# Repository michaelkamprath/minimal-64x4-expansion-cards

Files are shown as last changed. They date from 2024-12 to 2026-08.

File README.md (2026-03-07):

# Expansion Cards for Minimal 64x4 Computer
This repository contains various expansion cards for the [Minimal 64x4 Home Computer](https://github.com/slu4coder/Minimal-64x4-Home-Computer/) design by Carsten Herting, known as [slu4 on YouTube](https://www.youtube.com/channel/UCXYQcMpUBT3aaQKfmAVJNow).

## Back Plane
The [back plane provided in this repository](./expansion-backplane/) allows for more than one expansion card to be connected to the Minimal 64x4. It also provides a more convenient barrel jack power connector with a on/off switch to power the Minimal 64x4.

## Cards

* [**Speech Synthesizer**](./speech-synthesizer/) - This board provides support for interfacing with a TMS5220C speech synthesizer. 
* [**Multiplier Card**](./multiplier/) - This board provides a hardware implimentation of 8-bit integer multiplications, significantly improving the speed of multiplications over software-implementations.
* [**Timer**](./timer/) - Counts the cycles of the Minimal 64x4's system clock to enable precision timing of events.

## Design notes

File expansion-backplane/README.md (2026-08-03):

# Expansion Backplane for Minimal 64x4 Computer

This backplane allows connecting of up to 4 expansion cards to the Minimal 64x4 computer. The [expansion connector](./hardware/expansion-connector/) is a convenient way to connect the backplane to the Minimal 64x4 computer.

### Shared `INH` Line
To have multiple cards connected to the backplane, they need to share the active high `INH` inhibit line. If multiple cards are emitting a LOW signal directly, and one emits a HIGH, contention will occur. To prevent such contention, the back plane uses a 74AHCT126 to arbitrate the `INH` signal's progression from a card to the Minimal 64x4's exansion port. Each of the buffers in the 74AHCT126 have their input signal tied high, and the each card's `INH` output us used to control the output enable for it's assigned buffer. In this way, when a card's `INH` output is low (not active), it's corresponding buffer has its output in a high-Z state. So if another card asserts it's `INH` line high, there won't be bus contention back to the card. But each card's active high `INH` signal is passed through to the Minimal 64x4. The downside is that each expansion card cannot monitor whether another card is asserting the `INH` signal. This is not deemed to be a signficant issues since Minimal 64x4 expansion board are generally memory mapped, and thus only one can be actively writing to the bus at a time.

### Card Address Assignment
The data bus has **no arbitration** — the `INH` scheme above protects only the inhibit line. Correctness depends entirely on one card decoding a given address. Because address lines settle at different times during a bus transition, a card can transiently match another card's address and drive the bus against it, so assign base addresses to maximize the **Hamming distance of the decoded address bits**, not the hex separation.

| Card | Base | Decoded `A7..A3` |
| --- | --- | --- |
| Multiplier | `$FED0` | `11010` |
| Timer | `$FE28` | `00101` |

**Failure signature** (seen 2026-08 with the timer at `$FEF0`, one bit from the multiplier): reads from the victim card return wrong values intermittently, writes and RAM are fine, results vary run to run *and* between builds as code shifts, and software-only builds are perfect. Diagnose by moving one card, not by debugging the software.

Two mechanisms produce this and are **not yet distinguished**: address-line skew, or the 74HCT688 comparator glitching its output during input transitions. If it's the latter, bit distance is only probabilistic protection and a gated `/G` or delayed enable is needed. To measure: reinstate the colliding address, run `multiplier/software/test_karatsuba_layers.min64x4` (fails ~30% of 65536 cases, so events are continuous), and trigger a logic analyzer on *the victim card's decode asserting while the address belongs to the other card*.

Note that CLK-gating a card's read output enable is **not** a fix: the address and `RI`/`RO` are set on the falling edge and the selected card must be driving the bus before the rising edge latches it, so the read enable has to be live during the settling window by design.

### Power Barrel Jack
The back plane provides a convenient standard 2.1 mm barrel jack you may use to connect to a regulated `5V` power supply to power the expansion cards and additionally power the Minimal 64x4 computer. If this barrel jack is connected to power, be sure to not connect the UART's `+5V` line to the Minimal 64x4 (still connect `GND`)

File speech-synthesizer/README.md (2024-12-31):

# TMS5220 Speech Synthesizer for Minimal 64x4 Computer
This project creates a TMS5220-based speech synthesizer board for the [Minimal 64x4](https://github.com/slu4coder/Minimal-64x4-Home-Computer) expansion port. The high-level design criteria are:

1. **Accommodate the “slow memory” nature of the TMS5220** by using hardware to buffer the interactions between the CPU and the TMS5220 such that the CPU is free to do other tasks while the TMS5220 processes data. This contrasts with typical 1980s computer hardware designs, which would halt the CPU while the TMS5220 processed data.
2. **Only support “external” speech data; PHROMs are not supported.** Not supporting PHROMs greatly simplifies the board and saves money, as original PHROMs are hard to come by in the modern age. Most games of the 1980s did not use PHROM data, instead providing their own LPC-encoded speech data.

This board supports both the TMS5220 and TMS5220C variants of the speech synthesizer chip.

## Hardware Design
The board responds to three memory-mapped addresses (the board is adjustable to set the `_` value below, but it defaults to `0xC`):

* `0xFE_0` – **TMS5220 Command Register**
  This address allows the host computer to write data to the TMS5220’s command register, which is used for sending “external speech” data to the TMS5220. In general, the host computer will write certain TMS5220 commands and speech data to this address.

* `0xFE_1` – **TMS5220 Status Register**
  This address allows the host computer to fetch the internal TMS5220 status register. To do that, the host computer writes some data to this address (any value, as the value is not actually used) to start the sequence of events to get the internal status from the TMS5220. When this is done, the status value will be readable by the host computer at this address. The status data being ready is indicated by the board’s `BUSY` line, which is readable at the **Board Status Register**. The `BUSY` line will be asserted high from the moment this address is written to until the status value is ready to be read.

* `0xFE_2` – **Board Status Register**
  This address exposes several internal states of this board, independent of the TMS5220, and can be read by the host computer at any time. The individual bits within the byte value read are below. Of these lines, the host computer generally only interacts with the `/INT` and `BUSY` bits.

  * **bit 0 – `BUSY`**
    Indicates whether the TMS5220 or the board, in general, is working on something. The host computer should not interact with the TMS5220 Command or Status registers while this bit is high.
  * **bit 1 – `/INT`**
    The current value of the active-low interrupt line coming out of the TMS5220. When this bit is low, it indicates that the TMS5220 requires attention. The specific issue can be determined by reading the TMS5220 Status Register.
  * **bit 2 – `/READY`**
    The current value of the active-low `READY` line out of the TMS5220. Host computer software should use the `BUSY` line to arbitrate interaction with the board, but the `READY` line is exposed here for diagnostic purposes.
  * **bit 3 – `WS`**
    The current status of the `WS` flip flop (active high). Exposed for diagnostic purposes.
  * **bit 4 – `RS`**
    The current status of the `RS` flip flop (active high). Exposed for diagnostic purposes.

* `0xFE_3` – **TMS5220C Reset** – *Currently Unimplemented*
  The TMS5220C variant can be reset by holding both the `/RS` and `/WS` lines low at the same time. This action has undefined results for the non-C TMS5220 variant.

### TMS5220 “Slow Memory” Issue
A key pin to understand on the TMS5220 is the `READY` signal at pin 18. The TMS5220 drives the `READY` pin low when it is ready to accept input or provide output to the host computer. When the `READY` pin is high, the TMS5220 is busy processing data and does not immediately act on—if not outright ignore—any interactions the CPU initiates. In many 1980s-era computers, the `READY` pin was connected to the CPU’s halt or wait-state pin, causing the CPU to stop while the TMS5220 processed data. This board takes a different approach. In some ways, this is necessary because the Minimal 64x4 has no line that would allow an accessory to pause or halt the CPU. However, this design choice is otherwise agnostic of that limitation.

As a result, data interactions between the host computer and the TMS5220 must be cached to handle the timing differences. The key to caching these CPU interactions is the ATF22V10C programmable logic chip and the 74HCT74 flip flops. The flip flops hold the `/WS` and `/RS` signals on the TMS5220, and the ATF22V10C is programmed to create a state machine that manages these flip flops. For example, here is the sequence of events for writing a byte of data to the TMS5220:

1. When the address bus is set to the memory-mapped address of `0xFEC0`, the 74HCT688s will assert this `MMAP` line, and the `M0` and `M1` address lines will be 0. To write to the TMS5220, the host computer `/RI` line will be asserted. The ATF22V10C’s programmable logic then asserts `WS_CLK`, which is the clock line that drives the `WS` flip flop, in turn asserting the active-low `/WS` line to the TMS5220. This tells the TMS5220 that we want to write data to its data lines.
2. At the same time `WS_CLK` causes the `WS` flip flop to set its state, `WS_CLK` also causes the data bus input 74HCT374 flip flop to load the contents of the host computer’s data bus. Because of this, the expansion board can capture and hold the data bus value the host computer is writing to the TMS5220, allowing the host computer to move on to other tasks while this flip flop holds the data bus value. Furthermore, the `/WS` line to the TMS5220 also drives the output enable on the 74HCT374 octal flip flop, so the buffered data will be held and driven onto the board’s internal data bus for the entire time `/WS` is low—even as the host computer does other work. This is the essence of the “slow memory” issue: the TMS5220 requires several host-computer clock cycles to read in the data, and its data lines must be held for the entire duration. The 74HCT374 flip flop buffers the data and holds the lines active as long as needed.
3. In response to the `/WS` line being asserted, the TMS5220 drives the `READY` line high. When this occurs, the ATF22V10C waits until the `READY` line transitions from high to low, which indicates that the TMS5220 has finished processing the input data. When the `READY` line goes low, the ATF22V10C then asserts `WS_RST`, the reset line for the `WS` flip flop. This brings `/WS` high, which tells the TMS5220 that the write operation is complete. It also disables the output enable on the 74HCT374 that was buffering the data. In this way, `/WS` remains asserted until the TMS5220 indicates it is done reading the data from the buffers, as indicated by the `READY` line.
4. During this entire sequence, the ATF22V10C asserts the `BUSY` line for the board, which can be read by the host computer at address `0xFE_2` via the 74HCT245. This allows the host computer to query the board to see if the TMS5220 is done processing data.

A similar sequence is used when reading data from the TMS5220, centered around the `/RS` line.

### Undocumented Timing Issues
The TMS5220 appears to have some timing requirements that are not documented in its datasheet. These requirements were exposed by the Minimal 64x4, which runs at a clock speed faster than the typical host computers for which the TMS5220 was designed. These undocumented timing requirements were determined empirically and could likely be tweaked further:

* **Read Cycle for Status Transfers to External Speech Data Write**
  The datasheet indicates that the `t_wait` after `/RS` goes high is 12 µs. However, I found that something closer to 175 µs was needed between a status read and a subsequent external speech data write.

* **External Speech Data Write to Read Cycle for Status Transfers**
  Similarly, extra time is needed between writing external speech data and then reading the TMS5220 status. Again, I found that about 175 µs was needed.

These values were “tweaked until it worked.” The issues seem related to switching modes of interaction with the TMS5220. By contrast, writing an external speech data byte after a prior external speech data byte does adhere to the timing diagrams in the TMS5220 datasheet. Further experimentation might uncover better or smaller delays for these undocumented requirements.

## Software Design
The provided `speechlib.min64x4` file contains all the subroutines needed to use this board on the Minimal 64x4 home computer:

* `speech_init`
  Call this to initialize the board.

* `speak_synchronous`
  Speaks the LPC data in a passed buffer synchronously. Push the following arguments on the stack (in push order):
  1. **Buffer End Address** – 2-byte end address of the data buffer
  2. **Buffer Start Address** – 2-byte start address of the data buffer

* `speech_start`
  Speaks the LPC data in a passed buffer asynchronously, after synchronously waiting for any currently active talking to finish. Push the following arguments on the stack (in push order):
  1. **Buffer End Address** – 2-byte end address of the data buffer
  2. **Buffer Start Address** – 2-byte start address of the data buffer

* `speech_start_if_not_talking`
  Speaks the LPC data in a passed buffer asynchronously if there is no currently active speech. Push the following arguments on the stack (in push order):
  1. **Buffer End Address** – 2-byte end address of the data buffer
  2. **Buffer Start Address** – 2-byte start address of the data buffer

* `speech_update_buffer`
  Call this periodically (about every 1 ms) to enable asynchronous speech. No arguments.

* `speech_get_status`
  Gets the contents of the TMS5220 status register, which is returned in the `A` register. The following bit masks are defined to help interpret the results:
  * `SPEECH_STATUS_TALK` – The TMS5220 is currently talking.
  * `SPEECH_STATUS_BUFFER_LOW` – The TMS5220 FIFO buffer is half-empty. More LPC data needs to be sent.
    *_Note_*: The `speech_update_buffer` function automatically updates the FIFO if needed.
  * `SPEECH_STATUS_BUFFER_EMPTY` – The TMS5220 FIFO buffer is empty.

# Compiling the Software
All software found in the [software](./software/) directory is compiled with [BespokeASM](https://github.com/michaelkamprath/bespokeasm), which supports the Minimal 64x4. [Carsten Herting](https://github.com/slu4coder), the creator of the Minimal 64x4, also provides an assembler for it, but that assembler is quite minimal. One key shortcoming is the inability to import library code into the current compilation. BespokeASM enables importing libraries and includes several other features that this project’s software depends on.

To compile the speech code in this repository, use the following command:

```sh
bespokeasm compile -c /path/to/bespokeasm/examples/slu4-minimal-64x4/slu4-minimal-64x4.yaml -n -p -t intel_hex lpc_player.min64x4
```
Where `/path/to/bespokeasm` is the path to the BespokeASM repository on your computer. This will produce an Intel HEX representation of the compiled program, which can then be sent to the Minimal 64x4 using its `receive` command.

# Resources
The following resources I found useful when putting together this project

* [TMS5220 Datasheet](./datasheets/tms5220.pdf) - Always consult the datasheet first.
* [Thierry Nouspikel's "The Speech Synthesizer module"](https://www.unige.ch/medecine/nouspikel/ti99/speech.htm) - A detailed overview of how the TMS5220 is used in the TI 99/4a.
* [TI 99/4a Development forum on AtariAge](https://forums.atariage.com/topic/352156-looking-for-help-on-tms5220-circuit-software-design-and-usage/) - These folks are legends, helpful and knowledgable about anything related to Texas Instruments.

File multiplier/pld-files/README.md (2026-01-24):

# `PLD` Files for Programmable Logic

## Compiling PLD
The `.pld` files in this directory may be compiled with [GALasm](https://github.com/daveho/GALasm) or [galette](https://github.com/simon-frankau/galette), producing a `.jed` file amonst others. Then the `.jed` file is used to program a `ATF16V8C` or `GAL16V8`.

```sh
galasm multiplier-board-controller.pld
```

## Programming the 22V10
The `ATF16V8C` type should be used when programming the ATF16V8C with `minipro`.

```sh
minipro -p "ATF16V8C" -w multiplier-board-controller.jed
```

## More Information
More information about programmable logic devices can be found at these links:
* [Understanding Programmable Logic - The GAL22V10](https://retrobrewcomputers.org/n8vem-pbwiki-archive/0/82152589/Programmable%20logic%20devices%20-%20v1.6.pdf) - A good overviews of what programmable logic devices are.
* [Galette](https://github.com/simon-frankau/galette) - an alternative GAL PLD assembler
* [GAL-ASM-Starterkit](https://www.mikrocontroller.net/attachment/20953/GAL-ASM-Starterkit_Manual.pdf) - Documentation the PLD file syntax from another PLD assembler.

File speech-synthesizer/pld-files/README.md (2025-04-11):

# `PLD` Files for Programmable Logic

## Compiling PLD
The `.pld` files in this directory may be compiled with [GALasm](https://github.com/daveho/GALasm), producing a `.jed` file amonst others. Then the `.jed` file is used to program a `ATF22V10C` or `GAL22V10`.

```sh
galasm minimal-64x4-speech-controller.pld
```

## Programming the 22V10
The `ATF22V10C(UES)` type should be used when programming the ATF22V10C with `minipro`.

```sh
minipro -p "ATF22V10C(UES)" -w minimal-64x4-speech-controller.jed
```

## More Information
More information about programmable logic devices can be found at these links:
* [Understanding Programmable Logic - The GAL22V10](https://retrobrewcomputers.org/n8vem-pbwiki-archive/0/82152589/Programmable%20logic%20devices%20-%20v1.6.pdf) - A good overviews of what programmable logic devices are.
* [Galette](https://github.com/simon-frankau/galette) - an alternative GAL PLD assembler
* [GAL-ASM-Starterkit](https://www.mikrocontroller.net/attachment/20953/GAL-ASM-Starterkit_Manual.pdf) - Documentation the PLD file syntax from another PLD assembler.

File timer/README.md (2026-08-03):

# Timer - Clock Counter
This Timer card provides a convenient way to capture precise timing on the Minimal 64x4 by counting clock cycles. The counter is resettable to 0, allowing specific operations to be timed. The counter is 48 bits wide, which allows time ranges up to about 1.1 years at the Minimal 64x4's 8 MHz clock frequency.

## Hardware Design
[This card](./hardware/) uses six 74HC590 8-bit counters arranged in a cascading carry chain to create a 48-bit counter. The 74HC590 has tri-state outputs, so each counter IC is connected directly to the data bus and remains in high-Z unless selected to drive its latched value. Card control is handled by two 74HC688 comparators (address decode) and an ATF22V10C programmable logic device (control logic for read byte select, latch, and reset). The combinational logic is captured in [the PLD code](./pld-files/).

## Memory Map

Define:

`base = $FE00 + (x << 4) + y`

Where:
- `y` is controlled by jumper `J1` (address bit A3): `J1` open => `y = 0`, `J1` bridged => `y = 8`.
- `x` is controlled by jumpers `J2`-`J5` (address bits A4-A7): `J2` is A4 (LSB of `x`) and `J5` is A7 (MSB of `x`).
- Jumpers are named from the PCB silkscreen (`J1`-`J5`).

| Offset From `base` | R/W | Function | Description |
| --- | ----- | --- | --- |
| `+0` | Read  | Latched Byte 0 | Read latched counter value, byte 0 (LSB) |
| `+1` | Read  | Latched Byte 1 | Read latched counter value, byte 1 |
| `+2` | Read  | Latched Byte 2 | Read latched counter value, byte 2 |
| `+3` | Read  | Latched Byte 3 | Read latched counter value, byte 3 |
| `+4` | Read  | Latched Byte 4 | Read latched counter value, byte 4 |
| `+5` | Read  | Latched Byte 5 | Read latched counter value, byte 5 (MSB) |
| `+6` | Write | Latch Counter  | Latch (snapshot) the current 48-bit counter into the output registers. Any value may be written to trigger this action. |
| `+7` | Write | Reset Counter  | Reset the counter value to `0`. Any value may be written to trigger this action. |

Concrete ranges for a selected `x`:
- `J1` open (`y = 0`): registers are at `$FEx0`-`$FEx7`.
- `J1` bridged (`y = 8`): registers are at `$FEx8`-`$FExF`.

Notes:
- Bridging all jumpers `J2` through `J5` sets `x` to `$F`; leaving them open sets `x` to `$0` (default).
- Reading `$FEx0`-`$FEx5` (or `$FEx8`-`$FExD` when `J1` is bridged) returns the last value latched by writing to the latch register, not necessarily the current counter value.
- Resetting the counter does not latch a `0` value.

### Default Jumper Setttings
The code in this repo assumes the timer card's base address is $FE28. This is accomplished by jumpering J1 and J3, and leaving the others open.

## Time Range
This card has a 48-bit counter that is read one byte at a time. Not all bytes need to be read, but reading fewer bytes reduces the effective time range captured. At the **Minimal 64x4**'s 8 MHz clock, the maximum time range by number of bytes read is shown in this table:

| Bytes | Bits | Max Seconds (s) | Approx Time |
| ----: | ---: | ---: | --- |
| 6 | 48 | 35184372.088832 | 407.22652996 days (~1.115 years) |
| 5 | 40 | 137438.953472 | 38.17748708 hours (~1.5907 days) |
| 4 | 32 | 536.870912 | 8.94784853 minutes |
| 3 | 24 | 2.097152 | 2.097152 seconds |
| 2 | 16 | 0.008192 | 8.192 ms |
| 1 | 8 | 0.000032 | 32 µs |

The latched bytes are arranged in little-endian order: `base + 0` is the LSB and `base + 5` is the MSB.

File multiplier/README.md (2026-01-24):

# Integer Multiplication Accelerator for the Minimal 64x4 Computer
This project enables hardware-accelerated multiplication on the [Minimal 64x4 Home Computer](https://github.com/slu4coder/Minimal-64x4-Home-Computer/), exploring how multiplication works at a fundamental level in both software and hardware, using the Minimal 64x4 homebrew computer as a real-world test platform. Starting with a classic shifted-add multiplication algorithm implemented entirely in assembly, the project demonstrates both the mechanics and performance limits of software-based multiplication on an 8-bit CPU.

To dramatically improve performance, a dedicated hardware multiplier card is designed and built using discrete 74-series logic. The board implements a fully combinational 8-bit × 8-bit multiplier with memory-mapped I/O, allowing the CPU to offload multiplication and receive a 16-bit result in just a few clock cycles. The design is then extended in software to support full 16-bit × 16-bit multiplication through careful carry management.

The impact of hardware acceleration is demonstrated using a Mandelbrot renderer, where thousands of multiplications per frame make performance differences immediately visible. By comparing software-only and hardware-accelerated runs on real hardware, the project shows how a simple, purpose-built coprocessor can transform computational performance on a retro-style system.

# Hardware Multiplier Design
The hardware multiplier is a memory-mapped expansion board for the Minimal 64x4 that implements an 8-bit × 8-bit unsigned multiplication entirely in combinational logic. The design uses a planar array of 74AHCT08 AND gates to generate all partial products, followed by a cascade of 74HCT283 4-bit adders to sum those partial products and propagate carries. Because the multiplier core is purely combinational, no clocking, state machine, or control logic is required; once valid operands are presented, the result settles after the inherent gate propagation delay.

Operands are latched from the system data bus using 74AHCT374 registers to isolate the combinational logic from the shared bus and to ensure stable inputs during computation. The 16-bit result is continuously driven internally and presented to the host system through 74AHCT245 bidirectional bus transceivers when the board is selected. Address decoding is handled using 74HCT688 magnitude comparators, with a small programmable logic device (ATF16V8) providing glue logic for timing, output enable control, and bus arbitration.

Worst-case propagation delay is dominated by carry propagation through the adder array and is approximately 160 ns, corresponding to roughly two CPU cycles on an 8 MHz Minimal 64x4. From the CPU’s perspective, multiplication is reduced to a small number of memory writes and reads, enabling a substantial performance improvement over the software-only shifted-add implementation.

```text
                     ┌─────────────────────────┐
                     │        CPU / BUS        │
                     │  Address • Data • Ctrl  │
                     └───────────┬─────────────┘
                                 │
                        Memory-Mapped I/O
                                 │
        ┌────────────────────────▼────────────────────────┐
        │            Hardware Multiplier Board            │
        │                                                 │
        │  ┌───────────────┐      ┌────────────────────┐  │
        │  │ Input Latch A │◄─────┤                    │  │
        │  │  (8-bit)      │      │                    │  │
        │  └───────────────┘      │                    │  │
        │                         │                    │  │
        │  ┌───────────────┐      │  Combinational     │  │
        │  │ Input Latch B │◄─────┤  Multiplier Core   │  │
        │  │  (8-bit)      │      │  (AND Plane +      │  │
        │  └───────────────┘      │   Adder Array)     │  │
        │                         │                    │  │
        │                         │                    │  │
        │                         └─────────┬──────────┘  │
        │                                   │             │
        │                          16-bit Result          │
        │                                   │             │
        │                    ┌──────────────▼────────────┐│
        │                    │  Output Bus Transceivers  ││
        │                    │       (16-bit)            ││
        │                    └──────────────┬────────────┘│
        │                                   │             │
        │  ┌──────────────────────────┐     │             │
        │  │ Address Decode & Control │◄────┘             │
        │  │ (Comparators + PLD)      │                   │
        │  └──────────────────────────┘                   │
        └─────────────────────────────────────────────────┘
```
The overall structure of the hardware multiplier is shown in the block diagram above. The board interfaces with the CPU exclusively through memory-mapped I/O on the shared system bus. Operand values are written by the CPU into two 8-bit input latches (Operand A and Operand B), which isolate the multiplier core from bus activity and continuously present stable inputs to the combinational logic.

At the center of the design is a purely combinational multiplier core composed of an AND-gate partial-product plane followed by an adder array that collapses those partial products into a 16-bit result. Because the core has no internal state, clocking, or control signals, the result is produced automatically as signals propagate through the logic once the operands are latched.

The 16-bit result is connected to the system data bus through output bus transceivers that are enabled only during valid read cycles. Address decoding and timing control logic ensure the board responds only within its assigned address range and never drives the bus outside of those cycles. From the CPU’s perspective, the hardware multiplier appears as a small set of deterministic, memory-mapped registers, with computation latency bounded solely by combinational propagation delay.

# Compiling the Software
All software found in the [software](./software/) directory is compiled with [BespokeASM](https://github.com/michaelkamprath/bespokeasm), which supports the Minimal 64x4. [Carsten Herting](https://github.com/slu4coder), the creator of the Minimal 64x4, also provides an assembler for it, but that assembler is quite minimal (by design). One key shortcoming is the inability to import library code into the current compilation. BespokeASM enables importing libraries and includes several other features that this project’s software depends on.

To compile the speech code in this repository, use the following command:

```sh
bespokeasm compile -c /path/to/bespokeasm/examples/slu4-minimal-64x4/slu4-minimal-64x4.yaml -n -p -t intel_hex -D USE_ACCELERATOR mandelbrot.min64x4
```
Where `/path/to/bespokeasm` is the path to the BespokeASM repository on your computer. You may remove the `-D USE_ACCELERATOR` if you wish to compile the program to use software-only multiplication.

This will produce an Intel HEX representation of the compiled program, which can then be sent to the Minimal 64x4 using its `receive` command.

# Video

A Homebrew GPU for a Homebrew CPU (https://youtu.be/M8dk0JpkrbY)

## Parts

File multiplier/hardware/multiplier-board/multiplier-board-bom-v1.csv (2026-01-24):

Reference | Qty | Value | DNP | Exclude from BOM | Exclude from Board | Footprint | Datasheet | Mouser Part Number
C1,C2,C3,C4,C5,C6,C7,C8,C9,C10,C11,C12,C13,C14,C15,C16,C17,C18,C19,C20,C21,C22,C23,C24,C25,C26,C27,C28,C29,C30,C31,C32,C33,C34,C35,C36,C37 | 37 | 100 nF |  |  |  | Capacitor_SMD:C_0805_2012Metric_Pad1.18x1.45mm_HandSolder | ~ | 80-C0805C104M5R
CN1 | 1 | ~ |  |  |  | Connector_PinHeader_2.54mm:PinHeader_2x16_P2.54mm_Horizontal |  | 538-90122-0128
JP1,JP2,JP4 | 3 | SolderJumper_2_Bridged |  | Excluded from BOM |  | Jumper:SolderJumper-2_P1.3mm_Bridged_RoundedPad1.0x1.5mm | ~ | ~
JP3 | 1 | SolderJumper_2_Open |  | Excluded from BOM |  | Jumper:SolderJumper-2_P1.3mm_Open_RoundedPad1.0x1.5mm | ~ | ~
RN1 | 1 | 10K |  |  |  | Resistor_THT:R_Array_SIP5 | http://www.vishay.com/docs/31509/csc.pdf | 652-4605M-1LF-10K
U1,U2,U3,U4,U5,U6,U7,U8,U11,U12,U13,U14,U15,U16,U17,U18 | 16 | 74AHCT08 |  |  |  | Package_SO:SOIC-14_3.9x8.7mm_P1.27mm | http://www.ti.com/lit/gpn/sn74LS08 | 771-AHCT08D118
U9,U10 | 2 | 74HCT688 |  |  |  | Package_SO:SOIC-20W_7.5x12.8mm_P1.27mm | http://www.ti.com/lit/gpn/sn74LS688 | 771-AHCT08D118
U19 | 1 | ATF16V10C |  |  |  | Package_DIP:DIP-20_W7.62mm_Socket | https://ww1.microchip.com/downloads/en/DeviceDoc/Atmel-0425-PLD-ATF16V8C-Datasheet.pdf | 771-AHCT08D118
U20,U28 | 2 | 74AHCT374 |  |  |  | Package_SO:SOIC-20W_7.5x12.8mm_P1.27mm | http://www.ti.com/lit/gpn/sn74LS374 | 771-AHCT3D118
U21,U22,U23,U24,U25,U26,U27,U29,U30,U31,U32,U33,U34,U35 | 14 | 74HCT283 |  |  |  | Package_SO:SOIC-16_3.9x9.9mm_P1.27mm | http://www.ti.com/lit/gpn/sn74LS283 | 595-CD74HCT283M96
U36,U37 | 2 | 74AHCT245 |  |  |  | Package_SO:SOIC-20W_7.5x12.8mm_P1.27mm | http://www.ti.com/lit/gpn/sn74LS245 | 771-AHCT245D118

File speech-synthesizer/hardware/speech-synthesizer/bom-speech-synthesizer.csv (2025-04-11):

Id | Designator | Footprint | Quantity | Designation | Mouser Part Number | Other Supplier
1 | C6,C4,C5,C9,C7,C10,C8 | C_Disc_D3.4mm_W2.1mm_P2.50mm | 7 | 100 nF | 810-FG18X7R1H104KNT6
2 | TP2,TP1 | TestPoint_Pad_D2.0mm | 2 | TestPoint | - | -
3 | U3 | DIP-20_W7.62mm_Socket | 1 | 74HCT245 | 595-SN74HCT245N
4 | U7,U8 | DIP-20_W7.62mm_Socket | 2 | 74HCT688 | 595-CD74HCT688E
5 | R3 | R_Axial_DIN0207_L6.3mm_D2.5mm_P10.16mm_Horizontal | 1 | 10K | 603-CFR25SJT-52A10K
6 | U5,U4 | DIP-20_W7.62mm_Socket | 2 | 74HCT374 | 595-SN74HCT374N
7 | RV1 | Potentiometer_Vishay_T73YP_Vertical | 1 | 100K | 72-T70YP-100K
8 | R1 | R_Axial_DIN0207_L6.3mm_D2.5mm_P10.16mm_Horizontal | 1 | 1K8 | 603-CFR-25JT-52-1K8
9 | U1 | DIP-28_W15.24mm_Socket | 1 | TMS5220C | - | https://www.arcadeshop.com/i/875/5220-speech-i.c..htm
10 | U2 | DIP-24_W7.62mm_Socket | 1 | ATF22V10C | 556-AF22V10C7PX
11 | CN1 | PinHeader_2x16_P2.54mm_Horizontal | 1 | ~ | 538-90122-0128
12 | C1 | C_Disc_D4.7mm_W2.5mm_P5.00mm | 1 | 1 µF | 594-K105M20X7RF53H5
13 | RN1 | R_Array_SIP5 | 1 | 10K | 652-4605M-1LF-10K
14 | J1 | Jack_3.5mm_CUI_SJ1-3523N_Horizontal | 1 | AudioJack3 | 490-SJ1-3523N
15 | U6 | DIP-14_W7.62mm_Socket | 1 | 74HCT74 | 595-SN74HCT74N
16 | P1 | -5V_Converter | 1 | ~ | - | https://www.ebay.com/itm/333623420733
17 | C2 | C_Disc_D4.7mm_W2.5mm_P5.00mm | 1 | 0.22 µF | 594-K224K20X7RF5UH5
18 | C3 | C_Disc_D5.0mm_W2.5mm_P2.50mm | 1 | 10 pF | 594-K100J15C0GH5TL2

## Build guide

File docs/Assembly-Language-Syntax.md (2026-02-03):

# General Assembler Syntax
The general syntax for a line of assembly code is one of the following forms:

```asm
{label:} instruction {operands} {; comment}

constant_assignment {; comment}

directive {; comment}

{directive} label: {; comment}

{label:} data_directive {data_value} {; comment}

; {comment}
```

Items in curly braces `{..}` are optional.

Additional notes:

* Comments are prefixed with a semicolon `;`. Any characters after and including the first semicolon on a line are considered comments.
* Each line may contain multiple instructions, labels, or directives, with these limitations:
    * Only one line comment is recognized per line.
    * Instructions can only be followed by other instructions or a line comment.
    * Preprocessor directives cannot share a line with any instruction, label, or other directive.
    * _While there may be scenarios where multiple instructions per line are useful, this is generally discouraged as it can make code harder to debug and error messages more confusing._
* Whitespace is generally ignored except where needed to separate parts of a line. Indentation can be used for readability with no impact on assembled code.
* There is no explicit limit on line length.
* File extensions are not interpreted by the compiler, but are used for syntax highlighting if supported by your editor. See [Installing Language Extensions](https://github.com/michaelkamprath/bespokeasm/wiki/Installation-and-Usage#installing-language-extensions) for more information.

## Numeric Literals
Numeric literals, whether immediate values or memory addresses, can be written in decimal, hexadecimal, binary, or as single character ordinal values:

| Type | Syntax |
|:--|--:|
| Decimal | `124` |
| Hex | `$7C` |
| Hex | `0x7C` |
| Hex | `7CH` |
| Binary | `b01111100` |
| Binary | `%01111100` |
| Character Ordinal | `'\|'` |

### Numeric Expressions

Numeric expressions that can be resolved at compile time are supported. A numeric expression can include numeric literals, address labels, constant labels, or numeric operators. Supported operators:

| Operator | Description | Comment |
|:-:|:--|:--|
| `+` | Addition | |
| `-` | Subtraction | If there is no value to the left of the operator, then the value to the right of the operator is negated. |
| `*` | Multiply | |
| `/` | Divide | |
| `%` | Modulo | Should be surrounded by whitespace to avoid confusion with binary numbers. |
| `&` | Bit-wise AND | |
| `\|` | Bit-wise OR | |
| `^` | Bit-wise XOR | |
| `>>` | Right shift | Shifts the bits of the value left of the operator right the number of times given by the value right of the operator. |
| `<<` | Left shift | Shifts the bits of the value left of the operator left the number of times given by the value right of the operator. |
| `BYTEx(..)` | Byte value | Returns the value of the `x`-th byte of the expression contained in parenthesis. The `x` can only be a single digit, so `BYTE0(..)` through `BYTE9(..)` are allowed. Uses 0-based indexing where 0 is least significant byte regardless of endian setting. |
| `LSB(..)` | LSB | Equivalent to `BYTE0(..)` |
| `(..)` | Grouping | Parentheses must be paired. |

Note that numeric expressions are not the same thing as an offset for a register indirect [addressing mode](#addressing-modes), though the offset value can be expressed as a numeric expression.

### Single Character Ordinals
The ASCII value of a single character may be used as an integer anywhere a numeric expression is allowed. Indicate a character ordinal by bounding the character with single quotes `'`. This does not work for multiple characters, nor with double quotes `"`.

## Labels
A label is a string resolved at compile time to a specific numeric value. Labels can use alphanumeric characters and underscores `_`, but cannot start with a number. All labels must be unique. A label cannot have the same name as any directive, and non-register labels cannot share a name with a register label.

### Label Types
#### Address Label
An address label represents a specific address in the byte sequence being assembled. It does not generate byte code on its own, but can be used as an instruction argument. The address is implied by its position in the code.

A label is any case-sensitive alphanumeric string immediately preceding a colon `:`. Only one label is allowed per line, but a label can be followed by a directive or instruction on the same line. For example:
```asm
a_label: .byte $22        ; directive on same line as label
```

#### Constant Label
A constant is a special label with an explicitly assigned numeric value. Constants can be placed anywhere in the code. Assignment uses `=` or `EQU`:

```asm
constant_var = 10204
constant_var EQU 10204
```

Constants may be assigned either numeric literals or any numeric expression resolvable at compile time (including other labels). Constant labels are case-sensitive.

#### Register Labels
A register label is defined in the [instruction set configuration file](./Instruction-Set-Configuration-File). It represents hardware registers in instruction operands. Address and constant labels cannot use a string declared as a register label.

### Label Scope
Both address labels and constant labels can be defined to be applicable only in a given scope. A scope defines to what extent a label is visible and usable by other lines of code. The allowed scopes are:

* **Global** - Visible everywhere. These labels are not prefixed with a `.` or `_`.
* * **Named** - User-defined scopes with custom prefixes that can be shared across files. See [Named Label Scopes](#named-label-scopes).
* **File** - Visible only in the same file. Use a leading `_` to indicate file scope.
* **Local** - Visible only between two non-local labels in the same file, or between a non-local label and an `.org` directive, or between a non-local label and the end of file. Use a leading `.` to indicate local scope.
  * Local labels cannot be defined before the first non-local label or between a `.org` and a non-local label.

**Scope Precedence:**
When resolving symbols, BespokeASM follows this precedence order:
1. Local scope (`.` prefix)
2. Named scopes in reverse activation order (uses named scope's defined prefix)
3. File scope (`_` prefix)
4. Global scope (no prefix)

#### Named Label Scopes
Named label scopes allow you to create custom symbol namespaces with user-defined prefixes. This is useful for organizing symbols in libraries and larger projects, making them accessible across multiple files.

##### Creating a Named Scope
The syntax for creating a new named label scope is:
```asm
#create-scope "scope-name" prefix="prefix_"
```
Where:
* `scope-name`: The name of the scope being created. This name may not contain white space. Using the same `scope-name` across multiple `#create-scope` statements in the same compilation is considered to be an error.
* `prefix`: The string that symbols need to be prefixed with to be included in the namespace. The `prefix=...` parameter is optional. If not included, the prefix value defaults to the underscore character (`_`). Named scopes with `_` prefix take precedence over built-in file scope. Scope prefixes cannot start with `.` to avoid confusion with local scope.

When this directive is encountered in compilation, the named scope is also activated as if the `#use-scope` directive was used.

**Important:** Labels and constants can only be **created into** a named scope in the same file where that named scope was created. This restriction allows libraries to control their namespace. If a different file activates the named scope and defines a label with that scope's prefix, the label will fall back to the normal scope hierarchy (global, file, or local scope) instead of being added to the named scope. Labels already in the named scope can still be **referenced** from any file that activates that scope.

##### Using a Named Scope
In order to activate a named label scope to be used in the current compilation file, the following syntax is used:
```asm
#use-scope "scope-name"
```
When `#use-scope` is encountered in compilation, then labels in the identified named label space are resolved on subsequent code lines until the named label space is deactivated or the end of the file. Name label space activation is valid only in the current file and does not project into any files loaded using `#include`.

**Forward References:** Named scopes can be activated with `#use-scope` **before** they are created with `#create-scope`. This is intentional and enables flexible library workflows where a main file can declare its dependencies at the top, then include library files that define those scopes later. The assembler will validate that all used scopes are eventually defined during compilation.

##### Deactivating a Named Scope
```asm
#deactivate-scope "scope-name"
```

##### Examples

**Basic Usage:**
```asm
; Define a graphics scope
#create-scope "graphics" prefix="gfx_"
#use-scope "graphics"

gfx_screen_width: .2byte 320    ; Goes to graphics named scope
global_config: .byte 100        ; Goes to global scope (no matching prefix)
_file_local: .byte 0            ; Goes to file scope (no matching prefix)

; Named scopes can be shared across files via #include
```

**File Restriction Example:**
```asm
; === library.asm ===
#create-scope "mylib" prefix="lib_"

lib_init: .byte 1               ; Creates label in mylib named scope
lib_version: .byte 2            ; Creates label in mylib named scope

; === main.asm ===
#use-scope "mylib"              ; Activate the scope for resolution
#include "library.asm"

; Can reference library labels
jmp lib_init                    ; Works! Resolves to label in mylib scope

; But cannot create labels into the library's scope
lib_custom: .byte 3             ; Does NOT go to mylib scope!
                                ; Falls back to global scope instead
```

**Underscore Prefix for Exporting Internal Symbols:**
```asm
; === mathlib.asm ===
; Use underscore prefix to "export" what would normally be file-local symbols
#create-scope "mathlib" prefix="_"

_multiply: .byte 100            ; Goes to mathlib named scope (not file scope!)
_divide: .byte 200              ; Goes to mathlib named scope (not file scope!)
_internal_flag: .byte 0         ; Also goes to mathlib named scope

; === main.asm ===
#use-scope "mathlib"            ; Activate mathlib scope
#include "mathlib.asm"

; Can now reference these "exported" symbols
call _multiply                  ; Works! Resolves from mathlib named scope
call _divide                    ; Works! Resolves from mathlib named scope

; Note: Named scope with _ prefix takes precedence over built-in file scope
```

**Forward Reference Pattern:**
```asm
; === main.asm ===
; Declare dependencies before they're defined
#use-scope "graphics"
#use-scope "audio"

gfx_buffer: .2byte 640          ; Tries to use graphics scope (not created yet)
                                ; Falls back to global since scope not created here

#include "graphics_lib.asm"     ; This file creates the "graphics" scope
#include "audio_lib.asm"        ; This file creates the "audio" scope

; Now can reference labels from those scopes
jmp gfx_init                    ; Resolves from graphics named scope
call snd_play                   ; Resolves from audio named scope
```

## Memory Zones
A named memory zone is a contiguous address range in the ISA's address space, identified by an alphanumeric string. Additional conditions:

* A named memory zone must be completely contained by the allowed memory space of the configured ISA.
* Multiple named memory zones may overlap with each other
* When byte code is assembled, multiple byte codes assigned to the same absolute memory address is a fatal error.
* Named memory zones are a compile time construct, and are intended to only be a means to manage memory ranges and byte code memory locations in assembly code.
* Memory zones have a start and end absolute memory address. Byte code assigned to that memory zone with an absolute address outside of the memory zone's range will be an error.
* A memory zone's name cannot be also used for any label.

### Global Memory Zone
By default, a memory zone named `GLOBAL` is defined to be the full range of memory addresses allowed by the instruction set configuration file. For example, if the ISA defines a 16-bit address type, then the `GLOBAL` memory zone will be addresses `0x0000` though `0xFFFF`. 

The `GLOBAL` memory zone can be redefined in the ISA configuration to be a subset of what is permitted by the memory address bit size.

## Instructions
Instruction are converted into byte code. It is composed of a specific instruction mnemonic and an option list of operands according to this format:
```
MNEMONIC [OPERAND1[, OPERAND2[...]]]
```

* Instructions mnemonics may compose of any alphabetic character or the following special characters: `.`. The first character of an mnemonic must be a alphabetic character.
* Instruction operands are separated by a comma
* Instruction operands supported types are configured in the [Instruction Set Configuration File](./Instruction-Set-Configuration-File#instructions).
* Instruction matching is not case sensitive.

### Addressing Modes
BespokeASM supports several addressing mode notations for instruction operands, though the precise meaning of each is defined by the instruction set configuration file and the hardware that the instruction set will run on.  Explained here is the nominal application of each addressing mode notation.

| Mode | Notation | Description | Decorator Placement | Hardware Expectations |
|:-:|:-:|:--|:-:|:--|
| Immediate |`numeric_expression` | A constant value to be used as an operand. The constant value is indicated by a numeric expression. | - | Values embedded I program byte code should be generally readable. |
| Indirect | `[numeric_expression]`| A value that resides at a memory address indicated by a constant value. The constant value memory address is indicated by a numeric expression. | - | Ability to set a memory address register or similar. |
|Deferred | `[[numeric_expression]]` | The numeric constant value indicated by a numeric expression represents an address at which is the value of another address  where the value of interest resides. Basically, this is a doubly dereferenced memory address. Note the use of double square brackets in the notation. | - | Ability to follow a doubly dereferenced memory address. |
| Register | `register_label` | The value in a specified register. The register is indicated by a [register label](#register-labels). | Adjacent to register label.</br>_e.g.:_ `a++` | Hardware registers that are generally accessible. |
| Indexed Register | `register_label + offset_operand ` | Indicates a value that is the combination of the register value and the offset operand value. The combination is nominally a sum (`+` operator). | - | Ability to combine a register value with any configured offset operand source. |
| Indirect Register | `[register_label + offset]`| The specified register contains a memory address where the value is. An offset can be provided which should be added to the value in the register get the memory address where the desired value is. The register is indicated by a [register label](#register-labels), and the offset is provided as a numeric expression and follows the register label with a `+` or `-` sign in between it and and the register label. | Adjacent to square brackets.</br>_e.g.:_ `[sc+5]++` | Hardware registers that can set the memory address used to access memory devices. In order to support offsets, there should be the ability to produce a memory address by adding a value to the register value without necessarily changing the register value. |
| Indirect Indexed Register | `[register_label + offset_operand]` | Similar to **Indirect Register**, except that the offset can be set by any other addressing mode operand. When the configure offset operand is a numeric type, this behaves the same as **Indirect Register** except that the offset can only be `+` to the register, and there are no bounds checking on the value. The true value of this addressing mode is when the offset operand is configured to be **Register**, **Indirect Register** or **Indirect** value. | Adjacent to square brackets.</br>_e.g.:_ `[sc+i]++` | Similar hardware needs as **Indirect Register**, with the general ability to set the offset value from any configured offset operand source. |
| Relative Address | `numeric_expression` or `{numeric_expression}` | Generates a relative address offset which is the difference between the expression value of this operand and the address value of current instruction, where this the current instruction's address value can be either be the program counter value before the instruction begins, or the program counter value after all machine code for the instruction has been loaded. Useful for relative jumps or data moves. Notation can be configured. |- | Should be able to do offsets against the program counter value. |

#### Decorators
Addressing mode notation that supports decorators are indicted in the table above. A decorator can be used to modify an operand or even the instruction's action on the operand. The precise meaning depends on how the instruction set is configured. A prefix decorator typically indicates that the modification should occur before the instruction is executed, while a postfix decorator indicate the modification occurs after the instruction occurs. **BespokeASM** will recognize an operand with a decorator as a whole different operand than if the decorator wasn't present. 

For example, consider the following two instructions:
```asm
mov [a],b
mov [a]+,b
```
A instruction set could be configured such that the first instruction means to move the value in register `b` into memory at the address indicated by register `a` (Indirect Register addressing mode), while the second instruction with the decorate could mean to move the value in register `b` into memory at the address indicated by register `a` and then increment the value in register `a` after the value copy has occurred. 

Here are the decorators that **BespokeASM** supports. There specific mean is configured in the instruction set configuration.

| Decorator | Typical Meaning | Prefix | Postfix |
|:--|:--|:-:|:-:|
|`+`| Increment | ✓ |  ✓ |
|`-`| Decrement | ✓ |  ✓ |
|`++`| Increment | ✓ |  ✓ |
|`--`| Decrement | ✓ |  ✓ |
|`!`| Custom | ✓ |  ✓ |
|`@`| Custom | ✓ |  ✓ |

## Directives
Directives tell the assembler to do specific things when creating the byte code. Directives start with a period `.` or a hash `#`. 

### Bytecode Addressing
#### Memory Zone Scope
By default, code in any given source file is assembled into the `GLOBAL` memory zone. To set the current memory zone scope to something different, the following directive is used:

```asm
.memzone <memory zone name>
```

Note that the `GLOBAL` memory zone name can be used this directive. Subsequent assembly code lines will be compiled into the indicated memory zone scope until the end of the current assembly file or another directive that changes the memory zone scope. Addresses assigned to the byte code will be per the code ordering. 

Non-contiguous uses of a given memory zone scope will be compiled as if the assembly code in each use instance was concatenated together in the order processed by the assembler.

If a source file that is currently using a non-`GLOBAL` memory zone includes another source file, that included source file will be compiled into the `GLOBAL` memory zone scope per normal file processing as described above. When compilation returns to the original source file that included the additional source file, compilation will continue using the same memory zone scope that was active when the `#include` directive was processed. This means that source files must always declare any non-`GLOBAL` memory zone scope they wish to use, and such declarations only persist for the scope of that source file.

#### Relative Origin within a Memory Zone
A relative origin within a memory zone can be set with the `.org` directive:

```asm
.org <address offset value> "<memory zone name>"
```

Where `<address offset value>` is the positive offset from the start of the specific memory zone, and `<memory zone name>` is the optional name of a memory zone. The `<memory zone name>` value is denoted by quotes so as to offset it from the `<address offset value>`, especially if that was set with an expression.

As an example, if a memory zone named "variables" is defined to be the range of `0x2000` through `0x2FFF`, then:

```asm
.org 0x0100 "variables"
```

Would be the same as setting the current origin to and absolute value of `0x2100`. 

When using `GLOBAL` as the `<memory zone name>` then `<address offset value>` will be interpreted as an offset form the start of the `GLOBAL` memory zone as it would with any other named memory zone. If the `GLOBAL` memory zone has not be redefined, the net effect is the same as using `.org` with an absolute address. However, if the start address of the `GLOBAL` memory zone has been redefined in the ISA configuration file, then `<address offset value>` will be applied as an offset from the redefined start of `GLOBAL`.

The effective absolute address represented in this form of the `.org` directive is validated against the overall valid address range defined by the `GLOBAL` memory zone. If the absolute address is outside this range, then **BespokeASM** will emit an error.

#### Absolute Origin
Using the `org` direction without specifying a `<memory zone name>` will cause the `<address offset value>` to be interpreted as an absolute address.

For example:

```asm
.org $3400
```

Will set the current address to $3400. This is an absolute address value and not an offset to the `GLOBAL` memory zone.

The address represented in this form of the `.org` directive is validated against the overall valid address range defined by the `GLOBAL` memory zone. If the address is outside this range, then **BespokeASM** will emit an error.

#### Page Align
The address used for the next emitted byte code can be set to the next arbitrarily-defined page boundary, which would be an address value that is a multiple of a given number. This is done using the `.align` directive with this format:

```asm
.align <page size>
```

Where `<page size>` is an optional expression indicating the size of the page the next byte code address should align to. If the `<page size>` expression is not provided, then the page size define in the instruction set configuration will be used.

### Bytecode
There are a few byte code generation directives supported:

| Directive | Description |
|:--|:--|
| `.fill N, Y` | Fills the next `N` words with the byte value `Y` |
| `.zero N` | Shorthand for `.fill N, 0` |
| `.zerountil X` | Fills the next words up to and including address `X` with the value of `0`. Will emit nothing if address `X` is less than the address location of this directive. |

### Data Directives
A data directive allows for explicitly set byte code. Like an instruction, its relative position in the assembly code defines its memory address, but unlike the instruction the byte code edited is directly defined in the assembly code. When paired with a label, a data directive can be used to define variables and other memory blocks.

The data directives have several forms, each indicating how much data is being defined:

| Directive | Data Value Size | Data Length | Multi-Word Endianness |
|:--|:-:|:--|:--|
| `.byte` | 1 byte | Variable | N/A |
| `.2byte` | 2 bytes | Variable | Default |
| `.4byte` | 4 bytes | Variable | Default |
| `.8byte` | 8 bytes | Variable | Default |
| `.16byte` | 16 bytes | Variable | Default |
| `.cstr` | 1 byte | Variable | N/A |
| `.asciiz` | 1 byte | Variable | N/A |

The syntax of usage is simply the directive followed the a data values to be written. More than one value can be provided by a comma separated list of values or labels/constants. The value assembled into the byte code will be masked by the data value size of the directive.

The `.byte`, `.cstr`, and `.asciiz` directives can be used to define character strings delineated by a `"` or `'`. Quotes and apostrophes within the quoted string should be escaped. The data values generated will be the ASCII values for each character in the string. Python-style character escapes (e.g., `\t`, `\n`, `\x21`) can be used. The `.cstr` and `.asciiz` directives can be used only with strings and will appends a configurable byte value to the end of the string. This terminating byte value defaults to zero (`0`), but [can be configured to be a different value](https://github.com/michaelkamprath/bespokeasm/wiki/Instruction-Set-Configuration-File#general).

For multi-byte types (`.2byte`, `.4byte`, etc), the multi-word endianness representation of each individual value uses the configured default multi-word endianness specified in the instruction set configuration file. 

This example includes a label to be used to make the data's address usable elsewhere in the assembly code:
```asm
const_value = $BE

single_bytes:
    .byte $DE
    .byte $AD
    .byte const_value
    .byte $EF
byte_list:
    .byte $DE, 0xAD, const_value, $EF
str_with_no_terminating_null:
    .byte "It\'s a test string"
str_with_terminating_null:
    .cstr "It\'s a test string"

int16_value:
	.2byte $dead, $beef

int32_value:
	.4byte $deadbeef
```
### Data and Word Size
Since **BespokeASM** is designed to be used with a variety of different CPUs, it can [support differing word sizes](./Instruction-Set-Configuration-File#data-words-and-endianness). The data directives describe data in specific 8-bit byte sizes. If the CPU's word size is larger than the individual data value, then each individual data value will be placed into the least signficant bits of a distinct word by default. For example, the following `.byte` declaration:

```asm
.byte $01, $02, $03, $04
```

Would be represented in 16-bit words as follows:

```
address 0: 0x0001
address 1: 0x0002
address 2: 0x0003
address 3: 0x0004
```

If the word size is smaller than the individual data value, then the data value will be subdivided into the least number of words needed to represent the data size, and then laid out according to the multi-word endianness. For example, if the word size is 16-bits and the multi-word endianness is `big`, then the following `.4byte` declaration:

```asm
.4byte $01020304
```

Would be represented in 16-bit words as follows:

```
address 0: 0x0102
address 1: 0x0304
```

#### String Data and Byte Packing
By default, strings in `.byte`, `.cstr`, and `.asciiz` directives are expanded so that each character (and the terminator for `.cstr`/`.asciiz`) is placed in its own word, regardless of the word size. For example, the following `.cstr` declaration:

```asm
.cstr "Hello, World!"
```

Would be represented in 16-bit words as follows:

```
address  0: 0x0048
address  1: 0x0065
address  2: 0x006c
address  3: 0x006c
address  4: 0x006f
address  5: 0x0020
address  6: 0x0057
address  7: 0x006f
address  8: 0x0072
address  9: 0x006c
address 10: 0x0064
address 11: 0x0021
address 12: 0x0000
```

Note that the last word is a terminating null byte.

_Note: The default behavior can be changed by enabling the [`string_byte_packing`](./Instruction-Set-Configuration-File#string-byte-packing-for-data-directives) option in the configuration file. When enabled, quoted strings in `.byte` and `.cstr` will be packed tightly into words, and the padding behavior is controlled by the [`string_byte_packing_fill`](./Instruction-Set-Configuration-File#string-byte-packing-for-data-directives) option. See the [Instruction Set Configuration File documentation](./Instruction-Set-Configuration-File#string-byte-packing-for-data-directives) for details and examples._

#### Embedded Strings
If the features [is enabled for the instruction set](https://github.com/michaelkamprath/bespokeasm/wiki/Instruction-Set-Configuration-File#general), a quoted string using double quotes `"` may be placed anywhere in the assembly code and byte code will be generated based on the UTF8 values of the string's characters follow with the string termination character configured for the ISA.  This effectively allows the creation of a `.cstr` without the `.cstr` directive. Note that single quotes `'` cannot be used for creating embedded strings.

### Preprocessor
#### Include Other Files
Additional assembly files other than the target file indicated in the command invocation can be included in the compilation. This is done with the `#include` preprocessor directive. The specific format is:
```asm
#include "filename.asm"
```
Where `filename.asm` is the name of the file desired to be included. BespokeASM will search the include directories to find a file with the indicated filename. The include directory list includes the directory that contains the target file identified on command invocation, and any additional include directories identified by arguments to the command invocation.

Include paths may include relative directories (e.g. `common/serial.asm`) and the POSIX path segments `.` and `..`. Resolution is performed relative to the file containing the `#include` first; if the file is not found there, the configured include directories are searched.

When an assembly file is included by this directive, it is functionally equivalent to the the contents of the included file be present where the `#include` directive is. If `.org` directives are used in the included file, care should be taken such that the address of instructions do not collide between source files. BespokeASM will error if it detects that two or more instructions occupy the same address.

The `#include` directive is affected by [conditional compilation](#compilation-control). If the `#include` directive appears inside an inactive conditional block (e.g., within `#if 0` ... `#endif`), the file will not be included.

The inclusion of assembly files can be nested. However, BespokeASM will error if any given file ends up being included more than once.

#### Require Language Version
An assembly source file can require a version check of the assembly language version as identified `identifier` key of [the General section](./Instruction-Set-Configuration-File#general) of the assembly language configuration file being used for compilation. This is done using a `#require` preprocessor directive. Failing to meet the version requirement will cause the assembly process to exit with an error.

The `#require` directive supports two syntax formats:

**Legacy String Format:**
```asm
#require "language-id comparator version-string"
```
where:
* `language-id` is the language `name` value in the `identifier` block of the general configuration section.
* `comparator` is a comparison operator, such as `>=`, `>`, `==`, etc. The most common comparison operator will be `>=`.
* `version-string` is a semantic version string, e.g. `1.2.3`

Examples:
```asm
#require "test-lang >= 0.5.0"
#require "test-lang < 1.0.0"
```

**Symbol-Based Format:**
```asm
#require symbol-expression comparator symbol-expression
```
This format uses the same [symbol expression](#language-version-symbols) syntax as compilation control directives and supports the built-in language version symbols.

The version check is done at the moment the line with the `#require` preprocessor directive is processed. This means any given code file can have multiple `#require` checks. This is useful if you want to enforce a version range.

Examples:
```asm
#require __LANGUAGE_NAME__ == test-lang
#require __LANGUAGE_VERSION__ >= 2.0.1
```

#### Creating Memory Zones
A memory zone can be defined with the following directive

```asm
#create_memzone <memory zone name> <start address> <end address>
```

Where `<memory zone name>` is an alphanumeric string with no spaces which will serve as the memory zone name, `<start address>` is the absolute address of the start of the memory zone, and `<end address>` is the absolute address of the end of the memory zone. Both `<start address>` and `<end address>` must be defined with integer literals.

Any defined memory zone must be fully contained in the `GLOBAL` memory zone. Defining multiple memory zones with the same name is an error.

#### Macros
C-like preprocessor macros can be defined with the `#define` directive. The syntax is:
```asm
#define <symbol> <value>
```
Where `<symbol>` is the symbol for the macro that can be used elsewhere in the code, and `<value>` is the replacement value for wherever that symbol is used. The `<value>` can be left empty, which is equivalent to assigning an empty string to be the replacement value for the `<symbol>`. If the replacement value is intend to be interpreted as a string, it should be quoted with either single or double quotes.

Later, when a defined `<symbol>` is used in code, **BespokeASM** will immediately replace the `<symbol>`'s text with the defined `<value>` for that `<symbol>`. If the `<symbol>` is not defined when that line of code is read, then no replacement occurs. Symbol replacement is done recursively, so if one preprocessor macro symbol's replacement value is a string that contains another preprocessor mark symbol, that second preprocessor macro symbol is then replaced. This continues until nor symbol replacement occurs. An error will be generated if a symbol replacement loop is detected (e.g., symbol A is replaced by symbol B, which itself is replaced by symbol A).

Note that parametric preprocessor macro symbols (e.g., `FOO(x)`) are not allowed. While this feature can be used to create simple code macros in code, complex and even parametric macros should be created with [Instructions Macros feature](https://github.com/michaelkamprath/bespokeasm/wiki/Instruction-Set-Configuration-File#instruction-macros). Similarly, these preprocessor macros can be used to define constants in code, but the [constant label feature](#constant-label) is a better way to do that. The primary use case for preprocessor macros is to define symbols that can be used in [compilation control](#compilation-control).

#### Language Version Symbols
BespokeASM provides built-in preprocessor symbols that expose information about the language defined in the ISA configuration file. These symbols are automatically available for use in [compilation control](#compilation-control) directives and the symbol-based format of the [`#require` directive](#require-language-version).

The following built-in symbols are available:

| Symbol | Description | Example Value |
|:--|:--|:--|
| `__LANGUAGE_NAME__` | The language name from the ISA configuration | `sap1-lang` |
| `__LANGUAGE_VERSION__` | The complete semantic version string | `1.2.3` |
| `__LANGUAGE_VERSION_MAJOR__` | The major version number | `1` |
| `__LANGUAGE_VERSION_MINOR__` | The minor version number | `2` |
| `__LANGUAGE_VERSION_PATCH__` | The patch version number | `3` |

These symbols can be used in expressions within `#if`, `#elif`, and `#require` directives to create conditional compilation based on language version. When used in comparisons, language name comparisons are typically done as string comparisons, while version number comparisons are done as numeric comparisons.

**Examples:**
```asm
#if __LANGUAGE_NAME__ == sap1-lang
    ; SAP-1 specific code
#endif

#if __LANGUAGE_VERSION_MAJOR__ >= 2
    ; Use newer features available in v2+
#elif __LANGUAGE_VERSION_MAJOR__ == 1
    #if __LANGUAGE_VERSION_MINOR__ >= 5
        ; Use features available in v1.5+
    #else
        ; Fallback for v1.0-1.4
    #endif
#else
    ; Fallback for older versions
#endif

#require __LANGUAGE_VERSION_MAJOR__ >= 1
#require __LANGUAGE_VERSION_MAJOR__ < 3
```

**Important Note:** Mixed expressions that combine language version symbols with complex operators (`&&`, `||`, parentheses for grouping) are not supported. For example:
```asm
; ❌ NOT SUPPORTED - will generate an error
#if __LANGUAGE_VERSION_MAJOR__ >= 1 && OTHER_SYMBOL == 2
#if (SYMBOL == 4) && (__LANGUAGE_VERSION_MAJOR__ >= 0)

; ✅ SUPPORTED - use separate blocks instead
#if __LANGUAGE_VERSION_MAJOR__ >= 1
#if OTHER_SYMBOL == 2
    ; Both conditions are true
#endif
#endif
```

#### Compilation Control
Control over which lines of assembly get compiled can be done with the C-like `#if`, `#elif`, `#else`, `#ifdef`, `#ifndef`, and `#endif` preprocessor directives. Individual lines of assembly are braced by compilation controls preprocessor directives, which control whether those lines of assembly will be compiled or not. Each can be used as follows:

* `#if <symbol-expression> <comparison> <symbol-expression>` - Initiates a compilation control block by performing a comparison between two symbol expressions.
* `#if <symbol-expression>` - Initiates a compilation control block by comparing a symbol expression to the implied comparison of `!= 0`
* `#elif <symbol-expression> <comparison> <symbol-expression>` - Optional. Must follow and `#if` or `#elif` compilation control directive in sequence. Creates a subordinate condition block by performing a comparison between two symbol expressions.
* `#elif <symbol-expression>` - Optional. Must follow and `#if` or `#elif` compilation control directive in sequence. Creates a subordinate condition block by comparing a symbol expression to the implied comparison of `!= 0`.
* `#ifdef <symbol>` - Initiate a compilation control block by determining if a preprocessor macro symbol is defined
* `#ifndef <symbol>` - Initiate a compilation control block by determining if a preprocessor macro symbol is not defined
* `#else` - Option. Creates a subordinate condition block that evaluates true only if all previous subordinate condition blocks in the overall compilation control block are false. Must follow a `#if`, `#elif`, `#else`, `#ifdef`, or `#ifndef`.
* `#endif` - Terminates a compilation control block. Must come at the a compilation control block.

A `<symbol-expression>` is an [expression](#numeric-expressions) that uses preprocessor macros, [language version symbols](#language-version-symbols), numeric values, and mathematical operators, but not code labels (address labels, constants, etc). Symbol expressions used in compilation control processor directives must resolve to numeric or string values.

**Important:** BespokeASM does not support complex boolean operators (`&&`, `||`) or parentheses for grouping within individual `#if` or `#elif` directives. Each directive can only contain a single comparison. To achieve complex conditional logic, use nested `#if` blocks as shown in the examples above.

**Examples with user-defined symbols:**
```asm
#define SYMBOL1 "test-string"
#define SYMBOL2 57

#if SYMBOL1 == "my string"
    mov a,1
#elif SYMBOL2 > 50
    mov a,2
#else
    mov a,3
#endif
```
In this example, only the `mov a,2` line will get compiled.

**Examples with language version symbols:**
```asm
#if __LANGUAGE_NAME__ == sap1-lang
    ; Include SAP-1 specific optimizations
    ldi zero
    out
#elif __LANGUAGE_NAME__ == z80-lang
    ; Include Z80 specific code
    ld a, 0
    out (0), a
#endif

#if __LANGUAGE_VERSION_MAJOR__ >= 2
    ; Use new instruction available in version 2.0+
    push [stack_ptr]
#else
    ; Use legacy instruction for older versions
    mov [stack_ptr], sp
    push sp
#endif
```

#### Bytecode Emission Control
The `#mute` and `#unmute` preprocessor directives can be used to control whether the byte code derived from code is included in certain outputs, notably the binary image and pretty printing with theIntel Hex or MinHex formats. This is useful when you have code that defines symbols to be used else where but the byte code resulting from the definition of those symbols should not be part of the final byte code results.

To suppress the emission of byte code from the subsequent code lines in a file, use the `#mute` preprocessor directive. To restore the emission of byte code from subsequent code lines, use the `#unmute` or `#emit` preprocessor directives. The mute and unmute actions stack within the scope of a code file. That is, if for example two `#mute` preprocessor directives have ben included in code, two subsequent `#unmute` or `#emit` preprocessor director are needed to restore byte code emission. The `#mute` directive has no impact on byte code resulting from code loaded subsequently from an `#include` directive. [Conditional compilation](#compilation-control) will control whether a `#mute` or `#unmute` preprocessor directive is applied.

#### Compile-time Printing
During compilation you can emit informational messages using the `#print` preprocessor directive. This is useful for surfacing configuration state, feature flags, or progress while assembling.

Syntax:
```asm
#print "message"
#print <min-verbosity> "message"
#print <min-verbosity> <color> "message"
#print <color> "message"
```

Behavior:
- Prints the quoted string to standard output.
- If `<color>` is provided, the message is colorized in the terminal output.
- Respects [conditional compilation](#compilation-control): messages are emitted only when the current condition block is active.
- Respects [bytecode emission control](#bytecode-emission-control): messages are suppressed while muted (`#mute`/`#unmute`).
- If `<min-verbosity>` is provided, the message is printed only when the assembler's log verbosity is greater than or equal to that integer as set by the `-v` command line option. If omitted, the message is always eligible to print (subject to the two controls above).
 - Allowed `<color>` values are: `black`, `red`, `green`, `yellow`, `blue`, `magenta`, `cyan`, `white`.

Examples:
```asm
#print "building utilities"
#print 2 "detailed build step"
#print yellow "warning-style message"
#print 2 cyan "detailed info"

#if FEATURE_ENABLED
  #print "feature enabled"
#endif

#mute
#print "this will not print"
#unmute
#print "mute lifted"
```

#### Compile-time Errors
The `#error` preprocessor directive emits an error message and immediately stops compilation.

Syntax:
```asm
#error
#error "message"
```

Behavior:
- Always emits an error message (no verbosity gating).
- The message is prefixed with `ERROR: <line info> -`.
- Respects [conditional compilation](#compilation-control) and [bytecode emission control](#bytecode-emission-control): it only triggers when the current block is active and not muted.
- If no message is provided, a default message of `encountered error directive` is used.

Example:
```asm
#ifndef FEATURE_X
  #error "FEATURE_X must be defined"
#endif
```

# Examples
## Ben Eater SAP-1
The following example using the instruction set for [Ben Eater's SAP-1 Breadboard CPU](https://eater.net/8bit). 
```asm
; Count by Loop
;
; For the Ben Eater SAP-1 breadboard CPU
;

zero = 0              ; constant value for 0
one = 1               ; constant value for 1

start:
  ldi zero            ; load value of 0 into A
  out                 ; display

add_loop:
  add increment       ; add current value at 0xF to A
  jc increment_step   ; increment the step if overflow
  out                 ; display
  jmp add_loop        ; loop

increment_step:
  lda increment       ; load current increment value
  add one_value       ; add 1 to increment value
  jc restart_loops    ; if it overflows, just reset everything
  sta increment       ; save updated increment value
  jmp start           ; restart counting

restart_loops:
  ldi one             ; load the value of 1 into register A
  sta increment       ; reset the increment value to 1
  jmp start           ; restart counting

one_value:
  .byte 1             ; 1 value needed for incrementing the increment value

increment:
  .byte 1             ; storage for the current increment value
```

## Recursion with Subroutines
Here is an example that employs an instruction set that enable subroutines (`call`, `rts`), a stack (`push`, `pop`) and indirect addressing modes. It uses 16-bit addressing and little endian. The example configuration file for this instruction set is here. Also assumes a memory map with `$0000` is the start of ROM and `$8000` is the start of RAM.

```asm

;
; Variables
;

.org $8000           ; variables should be in RAM
n_value:
  .byte 5            ; N value to calculate factorial for

;
; Code
;

.org 0               ; code goes in ROM
start:
  push [n_value]     ; push the value at n_value onto the stack
  call factorial     ; jump to the factorial subroutine
  out                ; factorial results are in A register. display it
  hlt                ; done

; factorial subroutine
;
; Input:
;   stack - function return pointer
;   stack+2 - The input N value to calculate factorial. A single 8-bit value
;
; Output:
;   A register - the results of the factorial calculation. A single 8-bit value
;
; Registers used: A
;
factorial:
  mov [sp+2],a      ; copy the N value to A register
  je .end,1       ; jump to f_stop if A is 1
  sub 1             ; subtract 1 from A to get (N-1)
  push a            ; put the n-1 value on the stack
  call factorial    ; recurse into factorial
  pop               ; remove the (N-1) value from stack
  push [sp+2]       ; push the N value on the stack
  push a            ; push the factorial(n-1) results on stack
  call multiply     ; call multiply subroutine
  pop               ; pop factorial(n-1) from stack
  pop               ; pop N-value from stack
.end:               ; local-scope label indicating the end of the subroutine
  rts               ; return from subroutine. Register A contains factorial(N)

; multiply subroutine
;
; Input:
;   stack - function return pointer
;   stack+2 - A single 8-bit value to multiply
;   stack+3 - A single 8-bit value to multiply
;
; Output:
;   A register - the results of the multiply calculation. A single 8-bit value
;
; Registers use: A, I
;
multiply:
  mov [sp+2],a     ; copy the multiplicand to A
  je .zero,0       ; jump to zero handler if multiplicand is 0
  mov a,b          ; copy multiplicand to B to set up for add loop
  mov [sp+3],i     ; copy multiplier to I
  dec i            ; decrement I for 0-based loop
  jc .zero         ; was multiplier zero? If so, carry was set on the dec so jump to m_zero
.loop:             ; local scope label indicating the start of the summation loop
  jz .end          ; jump to done if multiplier counter is now zero
  add b            ; add b to a
  dec i            ; decrement multiplier counter
  jmp .loop        ; restart addition loop
.zero:             ; local scope label indicating when a 0-multiplicand is handled
  mov a,0          ; set the return value to zero
.end:              ; local-scope label indicating the end of the subroutine
  rts              ; return from subroutine
```

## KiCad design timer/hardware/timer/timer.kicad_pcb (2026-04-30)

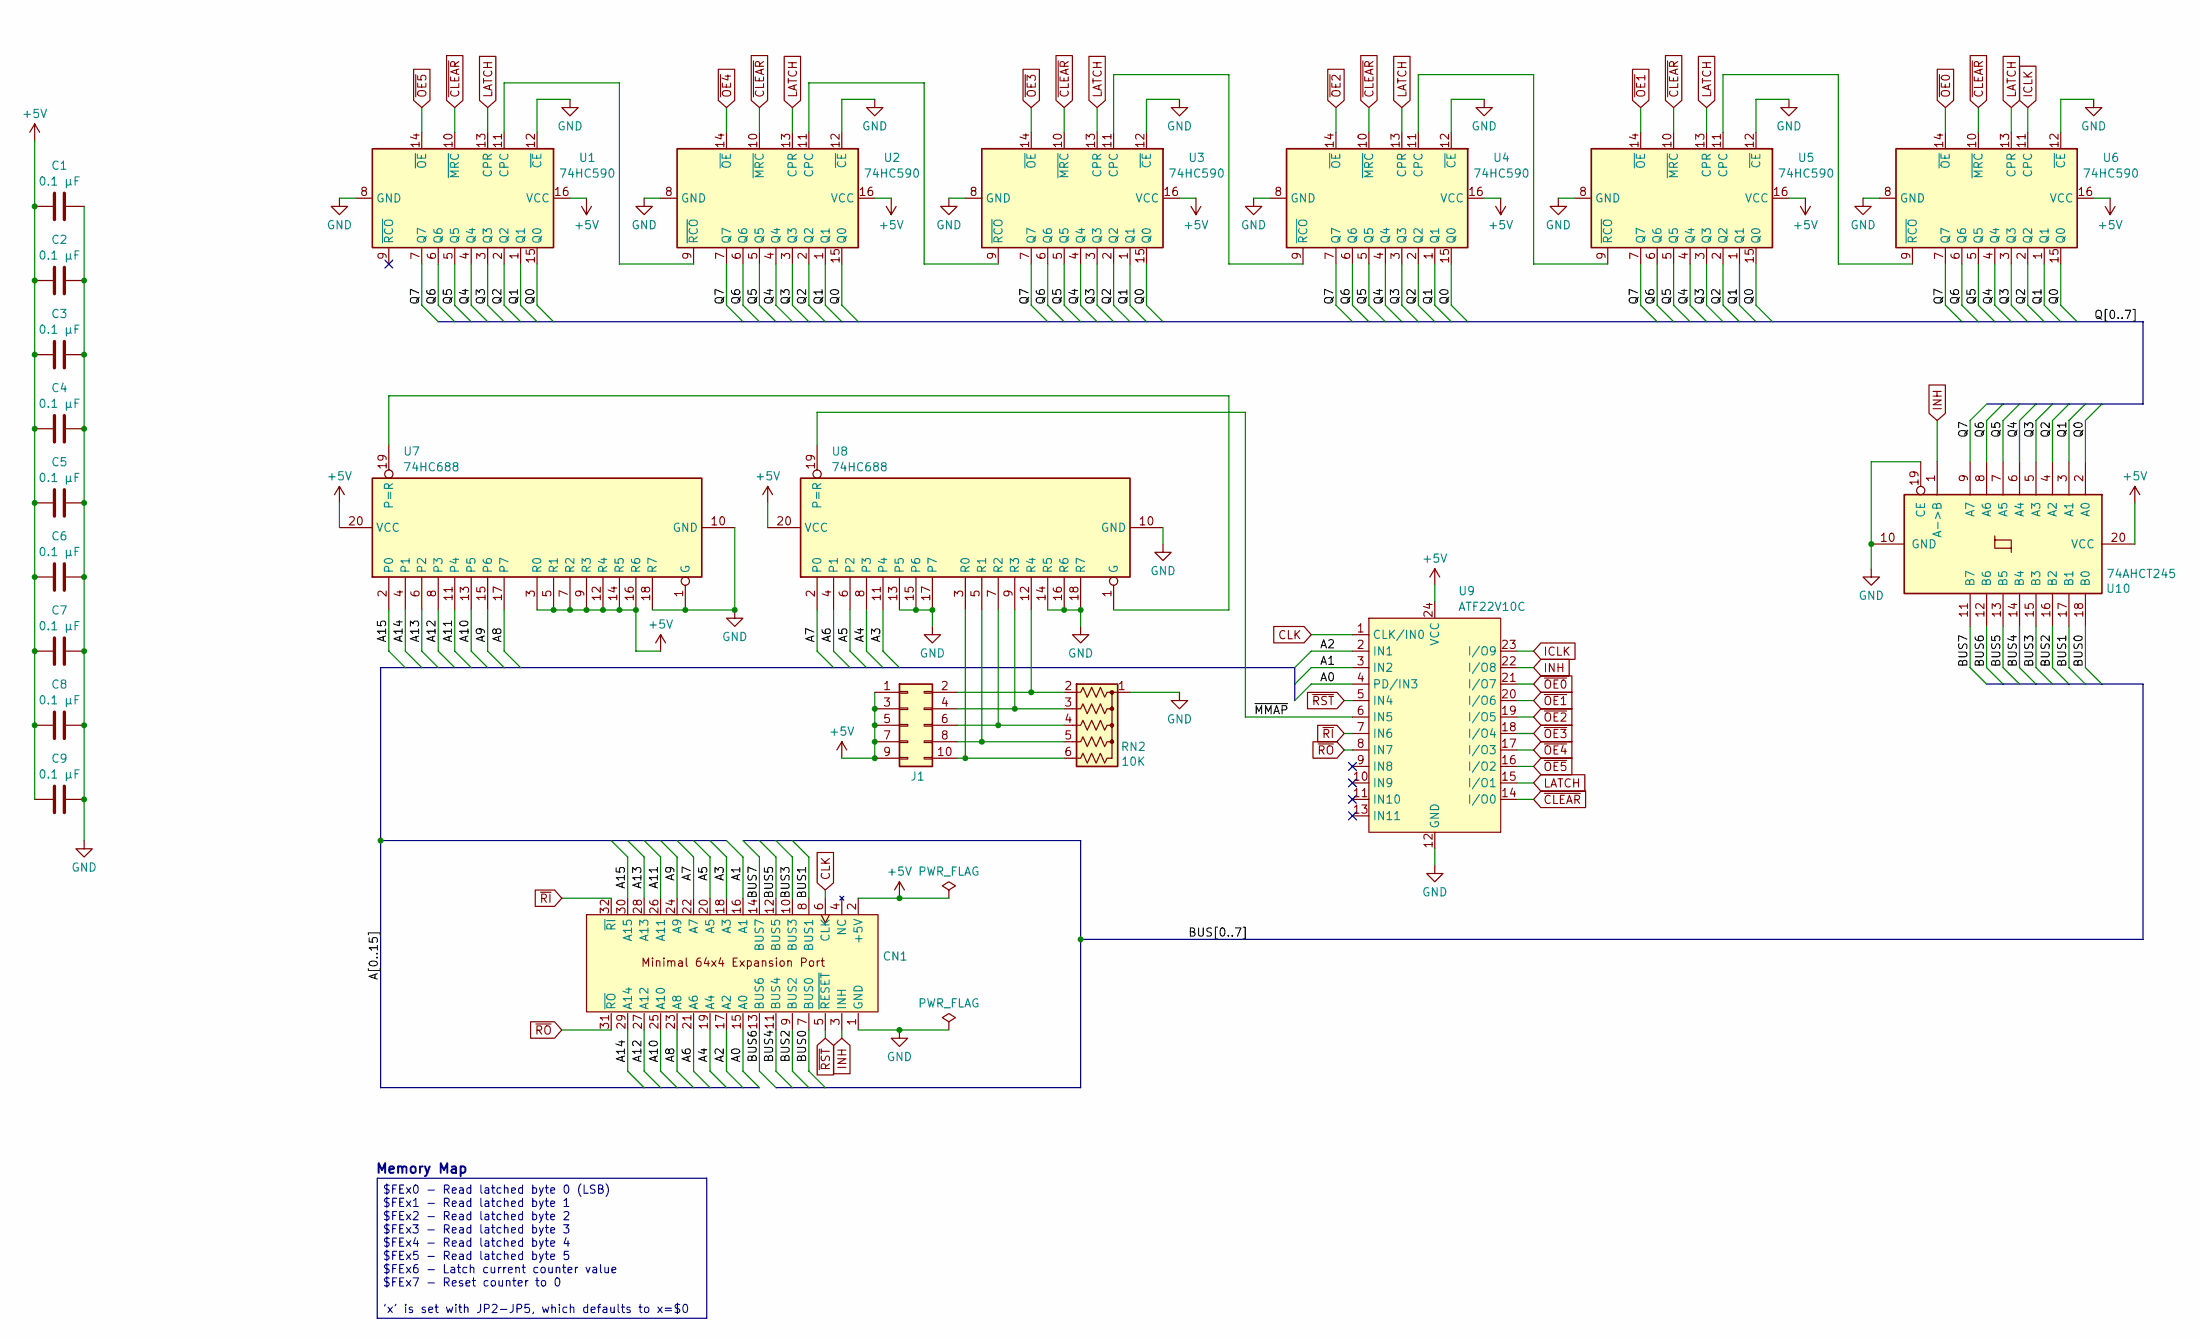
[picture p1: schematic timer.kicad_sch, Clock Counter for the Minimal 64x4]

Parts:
C1, C2, C3, C4, C5, C6, C7, C8, C9: 0.1 µF; C_Disc_D3.4mm_W2.1mm_P2.50mm
CN1: PinHeader_2x16_P2.54mm_Horizontal
J1: Conn_02x05_Odd_Even; PinHeader_2x05_P2.54mm_Vertical
RN2: 10K; R_Array_SIP6
U1, U2, U3, U4, U5, U6: 74HC590; DIP-16_W7.62mm_Socket
U7, U8: 74HC688; DIP-20_W7.62mm_Socket
U9: ATF22V10C; DIP-24_W7.62mm_Socket
U10: 74AHCT245; DIP-20_W7.62mm_Socket

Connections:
+5V: C1.1, C2.1, C3.1, C4.1, C5.1, C6.1, C7.1, C8.1, C9.1, CN1.2 (+5V), J1.1, J1.3, J1.5, J1.7, J1.9, U1.16 (VCC), U2.16 (VCC), U3.16 (VCC), U4.16 (VCC), U5.16 (VCC), U6.16 (VCC), U7.3 (R0), U7.5 (R1), U7.7 (R2), U7.9 (R3), U7.12 (R4), U7.14 (R5), U7.16 (R6), U7.20 (VCC), U8.20 (VCC), U9.24 (VCC), U10.20 (VCC)
/A0: CN1.15 (A0), U9.4 (PD/IN3)
/A1: CN1.16 (A1), U9.3 (IN2)
/A2: CN1.17 (A2), U9.2 (IN1)
/A3: CN1.18 (A3), U8.11 (P4)
/A4: CN1.19 (A4), U8.8 (P3)
/A5: CN1.20 (A5), U8.6 (P2)
/A6: CN1.21 (A6), U8.4 (P1)
/A7: CN1.22 (A7), U8.2 (P0)
/A8: CN1.23 (A8), U7.17 (P7)
/A9: CN1.24 (A9), U7.15 (P6)
/A10: CN1.25 (A10), U7.13 (P5)
/A11: CN1.26 (A11), U7.11 (P4)
/A12: CN1.27 (A12), U7.8 (P3)
/A13: CN1.28 (A13), U7.6 (P2)
/A14: CN1.29 (A14), U7.4 (P1)
/A15: CN1.30 (A15), U7.2 (P0)
/BUS0: CN1.7 (BUS0), U10.18 (B0)
/BUS1: CN1.8 (BUS1), U10.17 (B1)
/BUS2: CN1.9 (BUS2), U10.16 (B2)
/BUS3: CN1.10 (BUS3), U10.15 (B3)
/BUS4: CN1.11 (BUS4), U10.14 (B4)
/BUS5: CN1.12 (BUS5), U10.13 (B5)
/BUS6: CN1.13 (BUS6), U10.12 (B6)
/BUS7: CN1.14 (BUS7), U10.11 (B7)
/Q0: U1.15 (Q0), U2.15 (Q0), U3.15 (Q0), U4.15 (Q0), U5.15 (Q0), U6.15 (Q0), U10.2 (A0)
/Q1: U1.1 (Q1), U2.1 (Q1), U3.1 (Q1), U4.1 (Q1), U5.1 (Q1), U6.1 (Q1), U10.3 (A1)
/Q2: U1.2 (Q2), U2.2 (Q2), U3.2 (Q2), U4.2 (Q2), U5.2 (Q2), U6.2 (Q2), U10.4 (A2)
/Q3: U1.3 (Q3), U2.3 (Q3), U3.3 (Q3), U4.3 (Q3), U5.3 (Q3), U6.3 (Q3), U10.5 (A3)
/Q4: U1.4 (Q4), U2.4 (Q4), U3.4 (Q4), U4.4 (Q4), U5.4 (Q4), U6.4 (Q4), U10.6 (A4)
/Q5: U1.5 (Q5), U2.5 (Q5), U3.5 (Q5), U4.5 (Q5), U5.5 (Q5), U6.5 (Q5), U10.7 (A5)
/Q6: U1.6 (Q6), U2.6 (Q6), U3.6 (Q6), U4.6 (Q6), U5.6 (Q6), U6.6 (Q6), U10.8 (A6)
/Q7: U1.7 (Q7), U2.7 (Q7), U3.7 (Q7), U4.7 (Q7), U5.7 (Q7), U6.7 (Q7), U10.9 (A7)
/~MMAP: U8.19 (P=R), U9.6 (IN5)
CLK: CN1.6 (CLK), U9.1 (CLK/IN0)
GND: C1.2, C2.2, C3.2, C4.2, C5.2, C6.2, C7.2, C8.2, C9.2, CN1.1 (GND), RN2.1 (common), U1.8 (GND), U1.12 (~CE), U2.8 (GND), U2.12 (~CE), U3.8 (GND), U3.12 (~CE), U4.8 (GND), U4.12 (~CE), U5.8 (GND), U5.12 (~CE), U6.8 (GND), U6.12 (~CE), U7.1 (G), U7.10 (GND), U7.18 (R7), U8.10 (GND), U8.13 (P5), U8.14 (R5), U8.15 (P6), U8.16 (R6), U8.17 (P7), U8.18 (R7), U9.12 (GND), U10.10 (GND), U10.19 (CE)
ICLK: U6.11 (CPC), U9.23 (I/O9)
INH: CN1.3 (INH), U9.22 (I/O8), U10.1 (A->B)
LATCH: U1.13 (CPR), U2.13 (CPR), U3.13 (CPR), U4.13 (CPR), U5.13 (CPR), U6.13 (CPR), U9.15 (I/O1)
unnamed: J1.2, RN2.2 (R1), U8.12 (R4)
unnamed: J1.4, RN2.3 (R2), U8.9 (R3)
unnamed: J1.6, RN2.4 (R3), U8.7 (R2)
unnamed: J1.8, RN2.5 (R4), U8.5 (R1)
unnamed: J1.10, RN2.6 (R5), U8.3 (R0)
unnamed: U1.11 (CPC), U2.9 (~RCO)
unnamed: U2.11 (CPC), U3.9 (~RCO)
unnamed: U3.11 (CPC), U4.9 (~RCO)
unnamed: U4.11 (CPC), U5.9 (~RCO)
unnamed: U5.11 (CPC), U6.9 (~RCO)
unnamed: U7.19 (P=R), U8.1 (G)
~CLEAR: U1.10 (~MRC), U2.10 (~MRC), U3.10 (~MRC), U4.10 (~MRC), U5.10 (~MRC), U6.10 (~MRC), U9.14 (I/O0)
~OE0: U6.14 (~OE), U9.21 (I/O7)
~OE1: U5.14 (~OE), U9.20 (I/O6)
~OE2: U4.14 (~OE), U9.19 (I/O5)
~OE3: U3.14 (~OE), U9.18 (I/O4)
~OE4: U2.14 (~OE), U9.17 (I/O3)
~OE5: U1.14 (~OE), U9.16 (I/O2)
~RI: CN1.32 (~RI), U9.7 (IN6)
~RO: CN1.31 (~RO), U9.8 (IN7)
~RST: CN1.5 (~RESET), U9.5 (IN4)

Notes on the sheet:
$FEx0 - Read latched byte 0 (LSB) $FEx1 - Read latched byte 1 $FEx2 - Read latched byte 2 $FEx3 - Read latched byte 3 $FEx4 - Read latched byte 4 $FEx5 - Read latched byte 5 $FEx6 - Latch current counter value $FEx7 - Reset counter to 0 'x' is set with JP2-JP5, which defaults to x=$0
Memory Map

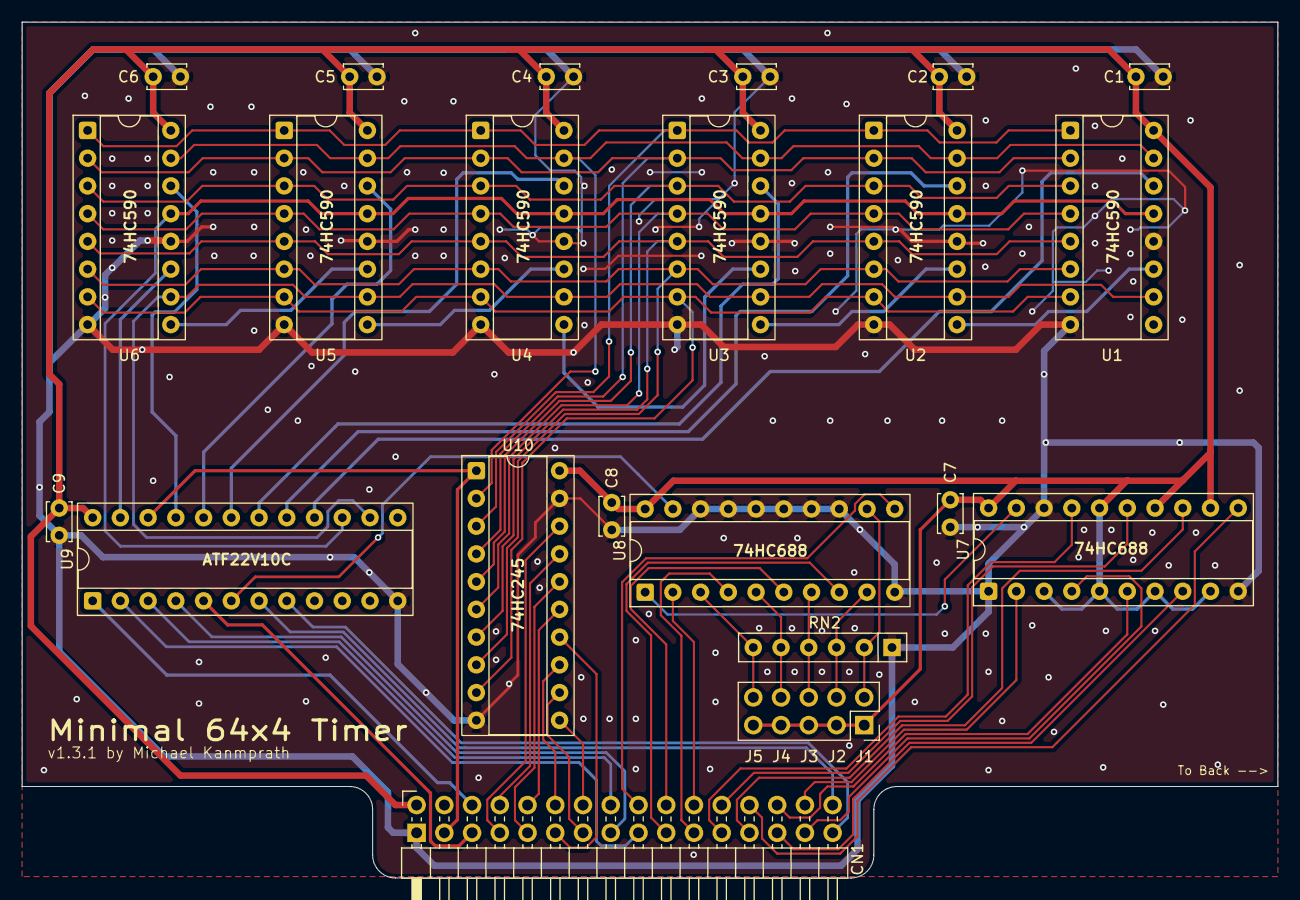
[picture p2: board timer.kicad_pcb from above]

Board: 2 copper layers, 115.0 x 78.4 mm, 22 parts (0 on the bottom side), 60 nets.

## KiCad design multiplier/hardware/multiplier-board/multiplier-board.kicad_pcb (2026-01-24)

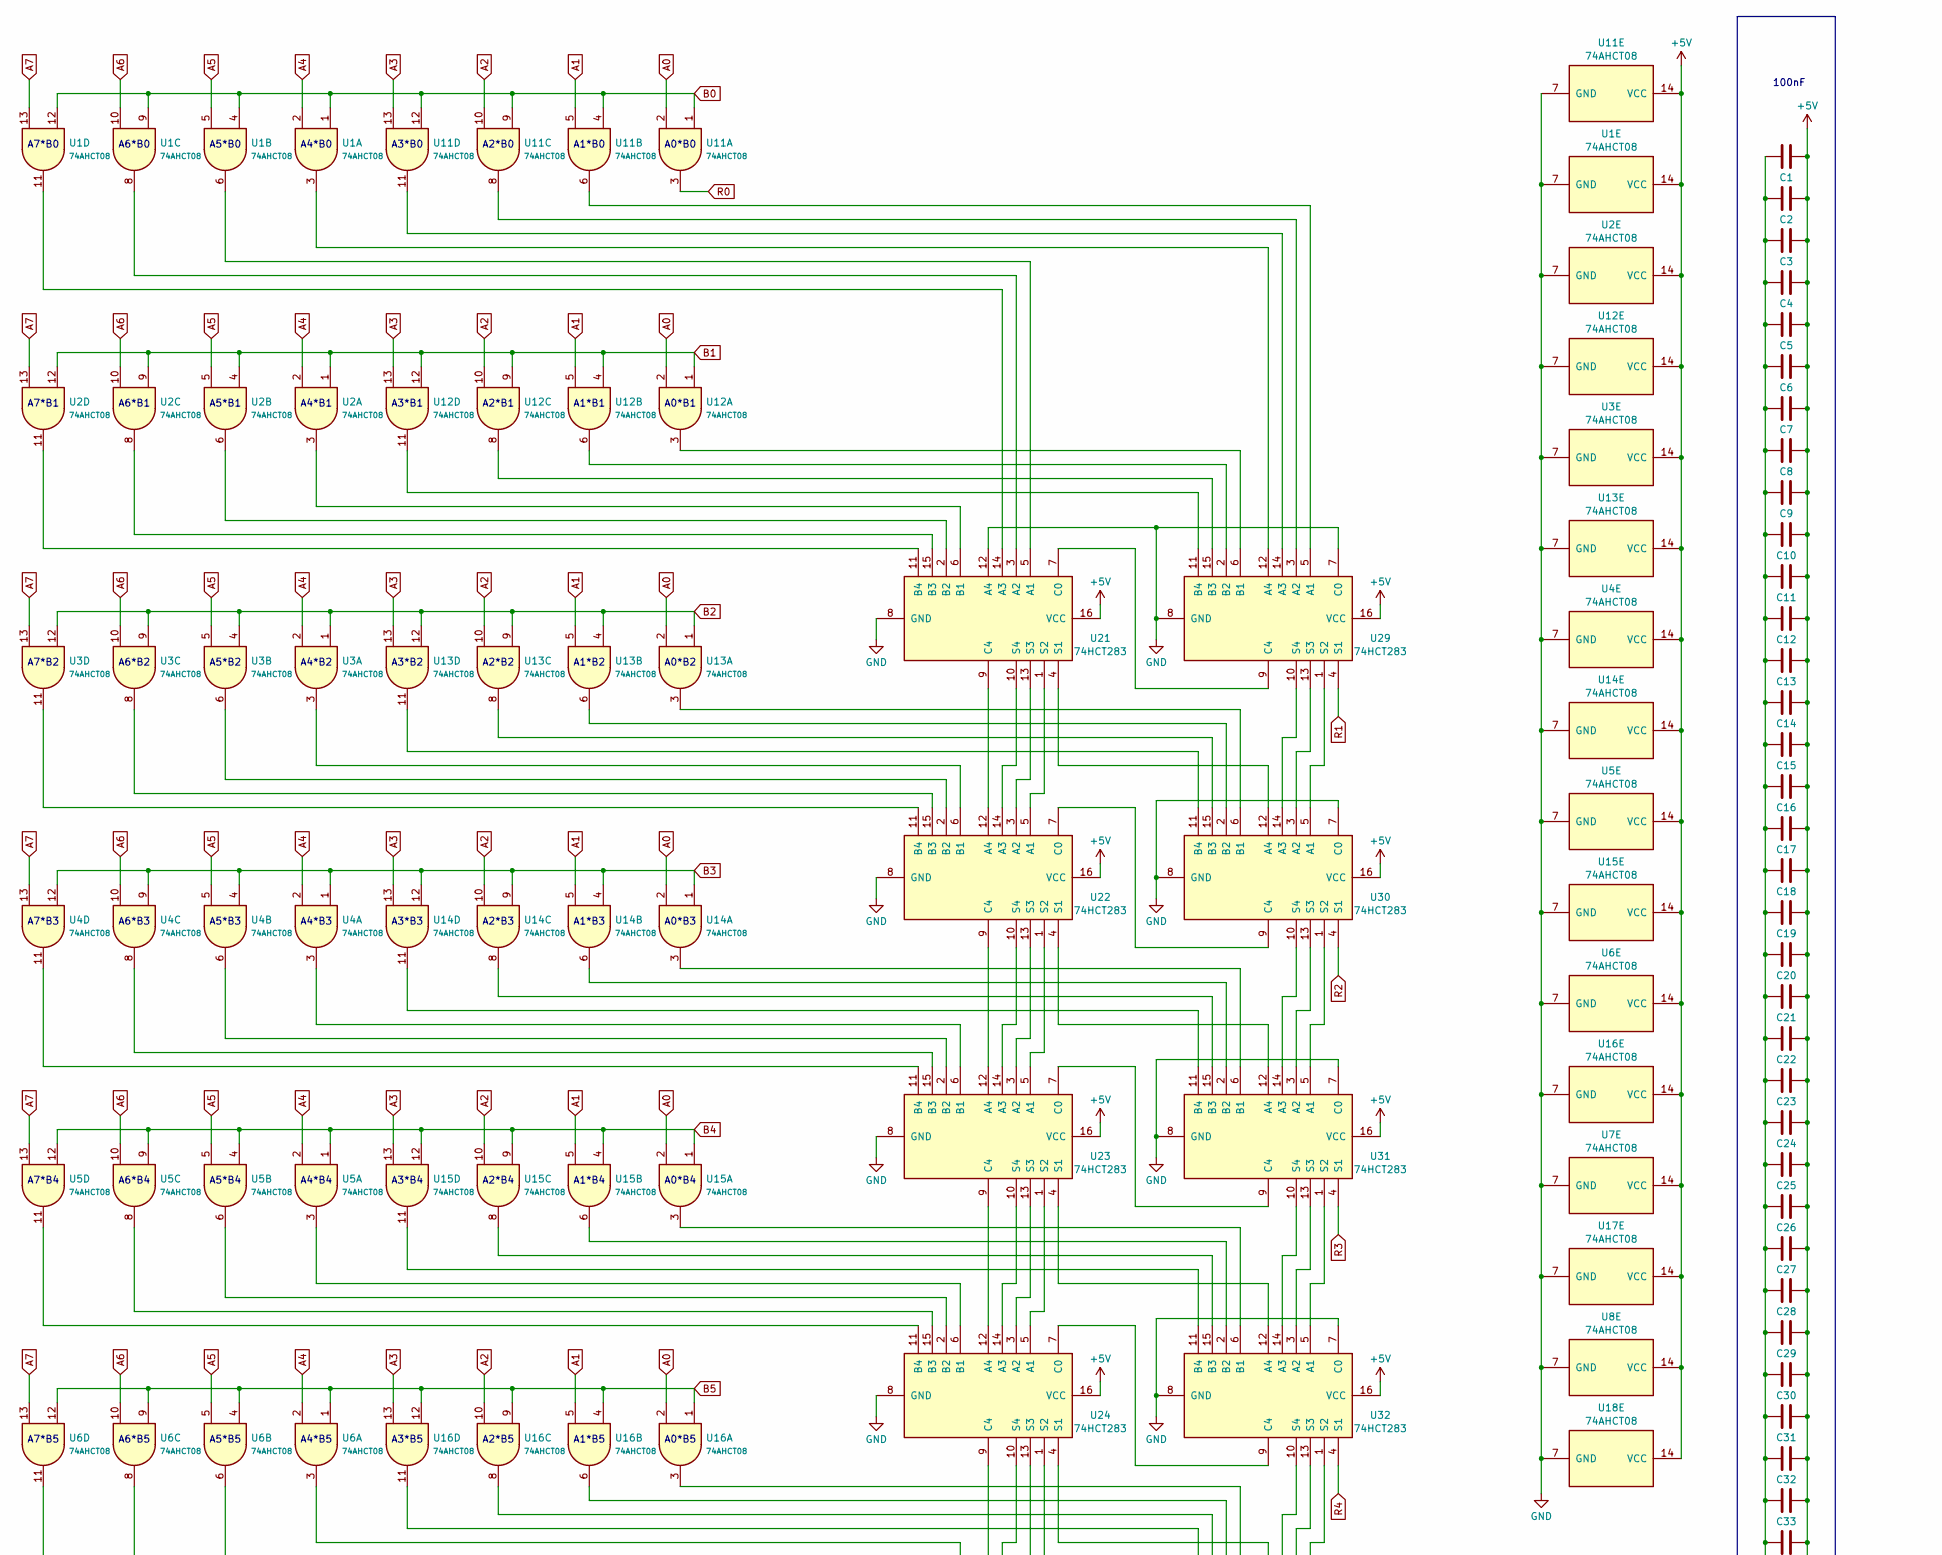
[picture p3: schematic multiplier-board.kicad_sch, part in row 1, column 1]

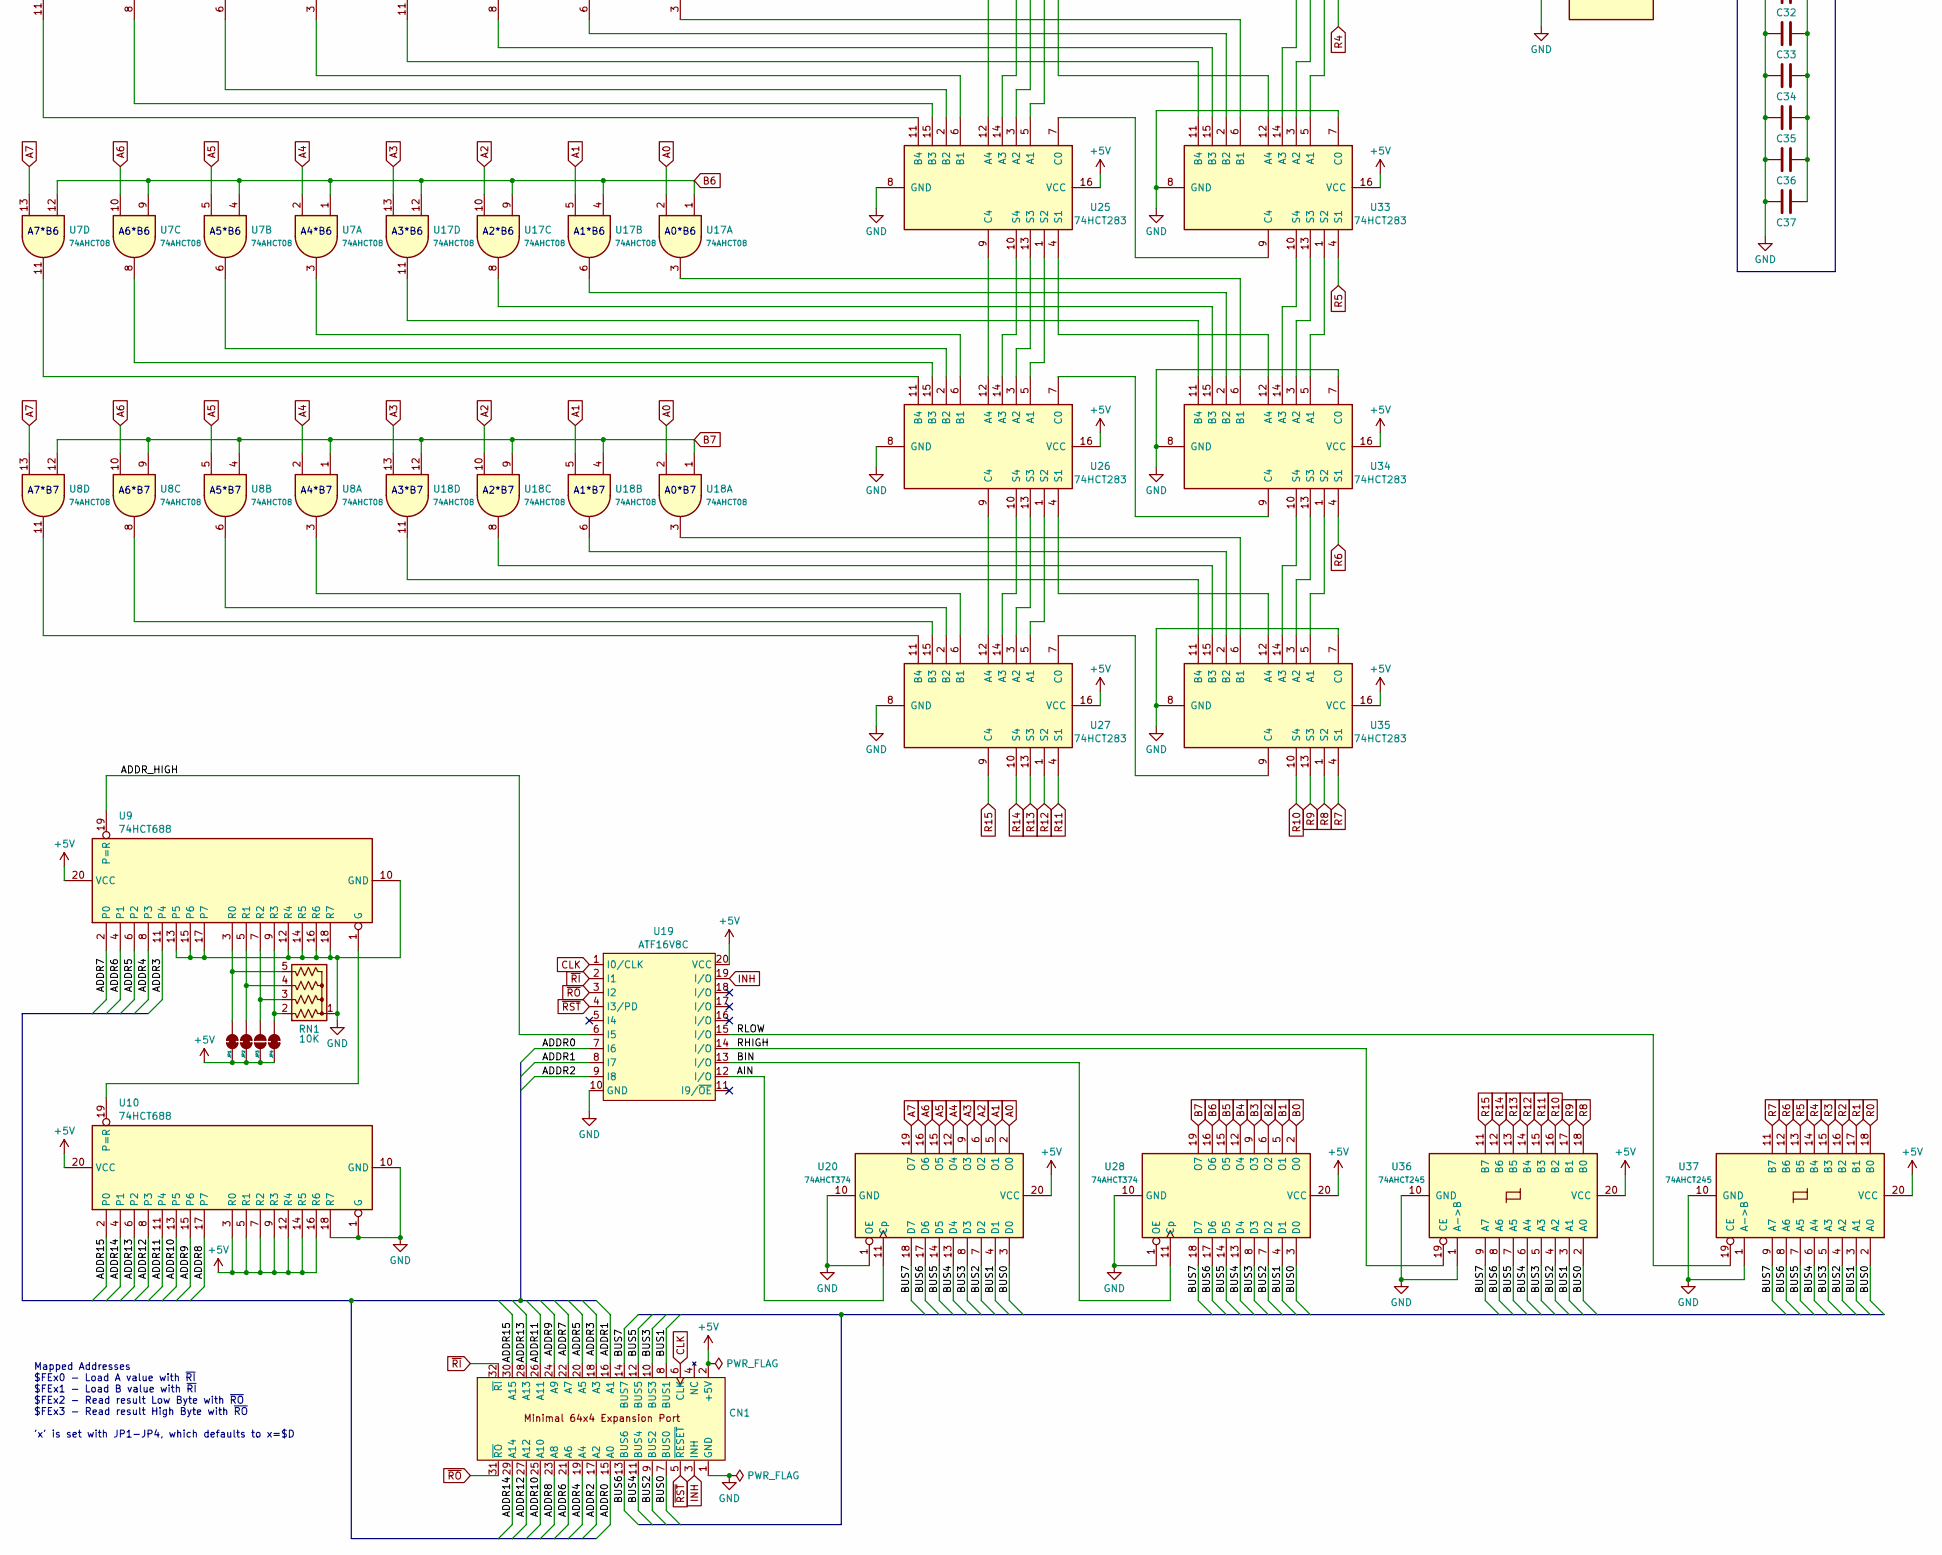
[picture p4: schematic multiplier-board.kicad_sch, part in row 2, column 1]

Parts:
C1, C2, C3, C4, C5, C6, C7, C8, C9, C10, C11, C12, C13, C14, C15, C16, C17, C18, C19, C20, C21, C22, C23, C24, C25, C26, C27, C28, C29, C30, C31, C32, C33, C34, C35, C36, C37: 100 nF; C_0805_2012Metric_Pad1.18x1.45mm_HandSolder
CN1: PinHeader_2x16_P2.54mm_Horizontal
JP1, JP2, JP4: SolderJumper_2_Bridged; SolderJumper-2_P1.3mm_Bridged_RoundedPad1.0x1.5mm
JP3: SolderJumper_2_Open; SolderJumper-2_P1.3mm_Open_RoundedPad1.0x1.5mm
RN1: 10K; R_Array_SIP5
U1, U2, U3, U4, U5, U6, U7, U8, U11, U12, U13, U14, U15, U16, U17, U18: 74AHCT08; SOIC-14_3.9x8.7mm_P1.27mm
U9, U10: 74HCT688; SOIC-20W_7.5x12.8mm_P1.27mm
U19: ATF16V8C; DIP-20_W7.62mm_Socket
U20, U28: 74AHCT374; SOIC-20W_7.5x12.8mm_P1.27mm
U21, U22, U23, U24, U25, U26, U27, U29, U30, U31, U32, U33, U34, U35: 74HCT283; SOIC-16_3.9x9.9mm_P1.27mm
U36, U37: 74AHCT245; SOIC-20W_7.5x12.8mm_P1.27mm

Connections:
+5V: C1.2, C2.2, C3.2, C4.2, C5.2, C6.2, C7.2, C8.2, C9.2, C10.2, C11.2, C12.2, C13.2, C14.2, C15.2, C16.2, C17.2, C18.2, C19.2, C20.2, C21.2, C22.2, C23.2, C24.2, C25.2, C26.2, C27.2, C28.2, C29.2, C30.2, C31.2, C32.2, C33.2, C34.2, C35.2, C36.2, C37.2, CN1.2 (+5V), JP1.1 (A), JP2.1 (A), JP3.1 (A), JP4.1 (A), U1.14 (VCC), U2.14 (VCC), U3.14 (VCC), U4.14 (VCC), U5.14 (VCC), U6.14 (VCC), U7.14 (VCC), U8.14 (VCC), U9.20 (VCC), U10.3 (R0), U10.5 (R1), U10.7 (R2), U10.9 (R3), U10.12 (R4), U10.14 (R5), U10.16 (R6), U10.20 (VCC), U11.14 (VCC), U12.14 (VCC), U13.14 (VCC), U14.14 (VCC), U15.14 (VCC), U16.14 (VCC), U17.14 (VCC), U18.14 (VCC), U19.20 (VCC), U20.20 (VCC), U21.16 (VCC), U22.16 (VCC), U23.16 (VCC), U24.16 (VCC), U25.16 (VCC), U26.16 (VCC), U27.16 (VCC), U28.20 (VCC), U29.16 (VCC), U30.16 (VCC), U31.16 (VCC), U32.16 (VCC), U33.16 (VCC), U34.16 (VCC), U35.16 (VCC), U36.20 (VCC), U37.20 (VCC)
/ADDR0: CN1.15 (A0), U19.7 (I6)
/ADDR1: CN1.16 (A1), U19.8 (I7)
/ADDR2: CN1.17 (A2), U19.9 (I8)
/ADDR3: CN1.18 (A3), U9.11 (P4)
/ADDR4: CN1.19 (A4), U9.8 (P3)
/ADDR5: CN1.20 (A5), U9.6 (P2)
/ADDR6: CN1.21 (A6), U9.4 (P1)
/ADDR7: CN1.22 (A7), U9.2 (P0)
/ADDR8: CN1.23 (A8), U10.17 (P7)
/ADDR9: CN1.24 (A9), U10.15 (P6)
/ADDR10: CN1.25 (A10), U10.13 (P5)
/ADDR11: CN1.26 (A11), U10.11 (P4)
/ADDR12: CN1.27 (A12), U10.8 (P3)
/ADDR13: CN1.28 (A13), U10.6 (P2)
/ADDR14: CN1.29 (A14), U10.4 (P1)
/ADDR15: CN1.30 (A15), U10.2 (P0)
/ADDR_HIGH: U9.19 (P=R), U19.6 (I5)
/AIN: U19.12 (I/O), U20.11 (Cp)
/BIN: U19.13 (I/O), U28.11 (Cp)
/BUS0: CN1.7 (BUS0), U20.3 (D0), U28.3 (D0), U36.2 (A0), U37.2 (A0)
/BUS1: CN1.8 (BUS1), U20.4 (D1), U28.4 (D1), U36.3 (A1), U37.3 (A1)
/BUS2: CN1.9 (BUS2), U20.7 (D2), U28.7 (D2), U36.4 (A2), U37.4 (A2)
/BUS3: CN1.10 (BUS3), U20.8 (D3), U28.8 (D3), U36.5 (A3), U37.5 (A3)
/BUS4: CN1.11 (BUS4), U20.13 (D4), U28.13 (D4), U36.6 (A4), U37.6 (A4)
/BUS5: CN1.12 (BUS5), U20.14 (D5), U28.14 (D5), U36.7 (A5), U37.7 (A5)
/BUS6: CN1.13 (BUS6), U20.17 (D6), U28.17 (D6), U36.8 (A6), U37.8 (A6)
/BUS7: CN1.14 (BUS7), U20.18 (D7), U28.18 (D7), U36.9 (A7), U37.9 (A7)
/RHIGH: U19.14 (I/O), U36.19 (CE)
/RLOW: U19.15 (I/O), U37.19 (CE)
A0: U11.2, U12.2, U13.2, U14.2, U15.2, U16.2, U17.2, U18.2, U20.2 (O0)
A1: U11.5, U12.5, U13.5, U14.5, U15.5, U16.5, U17.5, U18.5, U20.5 (O1)
A2: U11.10, U12.10, U13.10, U14.10, U15.10, U16.10, U17.10, U18.10, U20.6 (O2)
A3: U11.13, U12.13, U13.13, U14.13, U15.13, U16.13, U17.13, U18.13, U20.9 (O3)
A4: U1.2, U2.2, U3.2, U4.2, U5.2, U6.2, U7.2, U8.2, U20.12 (O4)
A5: U1.5, U2.5, U3.5, U4.5, U5.5, U6.5, U7.5, U8.5, U20.15 (O5)
A6: U1.10, U2.10, U3.10, U4.10, U5.10, U6.10, U7.10, U8.10, U20.16 (O6)
A7: U1.13, U2.13, U3.13, U4.13, U5.13, U6.13, U7.13, U8.13, U20.19 (O7)
B0: U1.1, U1.4, U1.9, U1.12, U11.1, U11.4, U11.9, U11.12, U28.2 (O0)
B1: U2.1, U2.4, U2.9, U2.12, U12.1, U12.4, U12.9, U12.12, U28.5 (O1)
B2: U3.1, U3.4, U3.9, U3.12, U13.1, U13.4, U13.9, U13.12, U28.6 (O2)
B3: U4.1, U4.4, U4.9, U4.12, U14.1, U14.4, U14.9, U14.12, U28.9 (O3)
B4: U5.1, U5.4, U5.9, U5.12, U15.1, U15.4, U15.9, U15.12, U28.12 (O4)
B5: U6.1, U6.4, U6.9, U6.12, U16.1, U16.4, U16.9, U16.12, U28.15 (O5)
B6: U7.1, U7.4, U7.9, U7.12, U17.1, U17.4, U17.9, U17.12, U28.16 (O6)
B7: U8.1, U8.4, U8.9, U8.12, U18.1, U18.4, U18.9, U18.12, U28.19 (O7)
CLK: CN1.6 (CLK), U19.1 (I0/CLK)
GND: C1.1, C2.1, C3.1, C4.1, C5.1, C6.1, C7.1, C8.1, C9.1, C10.1, C11.1, C12.1, C13.1, C14.1, C15.1, C16.1, C17.1, C18.1, C19.1, C20.1, C21.1, C22.1, C23.1, C24.1, C25.1, C26.1, C27.1, C28.1, C29.1, C30.1, C31.1, C32.1, C33.1, C34.1, C35.1, C36.1, C37.1, CN1.1 (GND), RN1.1 (common), U1.7 (GND), U2.7 (GND), U3.7 (GND), U4.7 (GND), U5.7 (GND), U6.7 (GND), U7.7 (GND), U8.7 (GND), U9.10 (GND), U9.12 (R4), U9.13 (P5), U9.14 (R5), U9.15 (P6), U9.16 (R6), U9.17 (P7), U9.18 (R7), U10.1 (G), U10.10 (GND), U10.18 (R7), U11.7 (GND), U12.7 (GND), U13.7 (GND), U14.7 (GND), U15.7 (GND), U16.7 (GND), U17.7 (GND), U18.7 (GND), U19.10 (GND), U20.1 (OE), U20.10 (GND), U21.8 (GND), U21.12 (A4), U22.8 (GND), U23.8 (GND), U24.8 (GND), U25.8 (GND), U26.8 (GND), U27.8 (GND), U28.1 (OE), U28.10 (GND), U29.7 (C0), U29.8 (GND), U30.7 (C0), U30.8 (GND), U31.7 (C0), U31.8 (GND), U32.7 (C0), U32.8 (GND), U33.7 (C0), U33.8 (GND), U34.7 (C0), U34.8 (GND), U35.7 (C0), U35.8 (GND), U36.1 (A->B), U36.10 (GND), U37.1 (A->B), U37.10 (GND)
INH: CN1.3 (INH), U19.19 (I/O)
unnamed: JP1.2 (B), RN1.5 (R4), U9.3 (R0)
unnamed: JP2.2 (B), RN1.4 (R3), U9.5 (R1)
unnamed: JP3.2 (B), RN1.3 (R2), U9.7 (R2)
unnamed: JP4.2 (B), RN1.2 (R1), U9.9 (R3)
unnamed: U9.1 (G), U10.19 (P=R)
unnamed: U1.6, U21.5 (A1)
unnamed: U1.8, U21.3 (A2)
unnamed: U1.11, U21.14 (A3)
unnamed: U2.3, U21.6 (B1)
unnamed: U2.6, U21.2 (B2)
unnamed: U2.8, U21.15 (B3)
unnamed: U2.11, U21.11 (B4)
unnamed: U21.7 (C0), U29.9 (C4)
unnamed: U21.9 (C4), U22.12 (A4)
unnamed: U21.4 (S1), U30.12 (A4)
unnamed: U21.1 (S2), U22.5 (A1)
unnamed: U21.13 (S3), U22.3 (A2)
unnamed: U21.10 (S4), U22.14 (A3)
unnamed: U3.3, U22.6 (B1)
unnamed: U3.6, U22.2 (B2)
unnamed: U3.8, U22.15 (B3)
unnamed: U3.11, U22.11 (B4)
unnamed: U22.7 (C0), U30.9 (C4)
unnamed: U22.9 (C4), U23.12 (A4)
unnamed: U22.4 (S1), U31.12 (A4)
unnamed: U22.1 (S2), U23.5 (A1)
unnamed: U22.13 (S3), U23.3 (A2)
unnamed: U22.10 (S4), U23.14 (A3)
unnamed: U4.3, U23.6 (B1)
unnamed: U4.6, U23.2 (B2)
unnamed: U4.8, U23.15 (B3)
unnamed: U4.11, U23.11 (B4)
unnamed: U23.7 (C0), U31.9 (C4)
unnamed: U23.9 (C4), U24.12 (A4)
unnamed: U23.4 (S1), U32.12 (A4)
unnamed: U23.1 (S2), U24.5 (A1)
unnamed: U23.13 (S3), U24.3 (A2)
unnamed: U23.10 (S4), U24.14 (A3)
unnamed: U5.3, U24.6 (B1)
unnamed: U5.6, U24.2 (B2)
unnamed: U5.8, U24.15 (B3)
unnamed: U5.11, U24.11 (B4)
unnamed: U24.7 (C0), U32.9 (C4)
unnamed: U24.9 (C4), U25.12 (A4)
unnamed: U24.4 (S1), U33.12 (A4)
unnamed: U24.1 (S2), U25.5 (A1)
unnamed: U24.13 (S3), U25.3 (A2)
unnamed: U24.10 (S4), U25.14 (A3)
unnamed: U6.3, U25.6 (B1)
unnamed: U6.6, U25.2 (B2)
unnamed: U6.8, U25.15 (B3)
unnamed: U6.11, U25.11 (B4)
unnamed: U25.7 (C0), U33.9 (C4)
unnamed: U25.9 (C4), U26.12 (A4)
unnamed: U25.4 (S1), U34.12 (A4)
unnamed: U25.1 (S2), U26.5 (A1)
unnamed: U25.13 (S3), U26.3 (A2)
unnamed: U25.10 (S4), U26.14 (A3)
unnamed: U7.3, U26.6 (B1)
unnamed: U7.6, U26.2 (B2)
unnamed: U7.8, U26.15 (B3)
unnamed: U7.11, U26.11 (B4)
unnamed: U26.7 (C0), U34.9 (C4)
unnamed: U26.9 (C4), U27.12 (A4)
unnamed: U26.4 (S1), U35.12 (A4)
unnamed: U26.1 (S2), U27.5 (A1)
unnamed: U26.13 (S3), U27.3 (A2)
unnamed: U26.10 (S4), U27.14 (A3)
unnamed: U8.3, U27.6 (B1)
unnamed: U8.6, U27.2 (B2)
unnamed: U8.8, U27.15 (B3)
unnamed: U8.11, U27.11 (B4)
unnamed: U27.7 (C0), U35.9 (C4)
unnamed: U11.6, U29.5 (A1)
unnamed: U11.8, U29.3 (A2)
unnamed: U11.11, U29.14 (A3)
unnamed: U1.3, U29.12 (A4)
unnamed: U12.3, U29.6 (B1)
unnamed: U12.6, U29.2 (B2)
unnamed: U12.8, U29.15 (B3)
unnamed: U12.11, U29.11 (B4)
unnamed: U29.1 (S2), U30.5 (A1)
unnamed: U29.13 (S3), U30.3 (A2)
unnamed: U29.10 (S4), U30.14 (A3)
unnamed: U13.3, U30.6 (B1)
unnamed: U13.6, U30.2 (B2)
unnamed: U13.8, U30.15 (B3)
unnamed: U13.11, U30.11 (B4)
unnamed: U30.1 (S2), U31.5 (A1)
unnamed: U30.13 (S3), U31.3 (A2)
unnamed: U30.10 (S4), U31.14 (A3)
unnamed: U14.3, U31.6 (B1)
unnamed: U14.6, U31.2 (B2)
unnamed: U14.8, U31.15 (B3)
unnamed: U14.11, U31.11 (B4)
unnamed: U31.1 (S2), U32.5 (A1)
unnamed: U31.13 (S3), U32.3 (A2)
unnamed: U31.10 (S4), U32.14 (A3)
unnamed: U15.3, U32.6 (B1)
unnamed: U15.6, U32.2 (B2)
unnamed: U15.8, U32.15 (B3)
unnamed: U15.11, U32.11 (B4)
unnamed: U32.1 (S2), U33.5 (A1)
unnamed: U32.13 (S3), U33.3 (A2)
unnamed: U32.10 (S4), U33.14 (A3)
unnamed: U16.3, U33.6 (B1)
unnamed: U16.6, U33.2 (B2)
unnamed: U16.8, U33.15 (B3)
unnamed: U16.11, U33.11 (B4)
unnamed: U33.1 (S2), U34.5 (A1)
unnamed: U33.13 (S3), U34.3 (A2)
unnamed: U33.10 (S4), U34.14 (A3)
unnamed: U17.3, U34.6 (B1)
unnamed: U17.6, U34.2 (B2)
unnamed: U17.8, U34.15 (B3)
unnamed: U17.11, U34.11 (B4)
unnamed: U34.1 (S2), U35.5 (A1)
unnamed: U34.13 (S3), U35.3 (A2)
unnamed: U34.10 (S4), U35.14 (A3)
unnamed: U18.3, U35.6 (B1)
unnamed: U18.6, U35.2 (B2)
unnamed: U18.8, U35.15 (B3)
unnamed: U18.11, U35.11 (B4)
R0: U11.3, U37.18 (B0)
R1: U29.4 (S1), U37.17 (B1)
R2: U30.4 (S1), U37.16 (B2)
R3: U31.4 (S1), U37.15 (B3)
R4: U32.4 (S1), U37.14 (B4)
R5: U33.4 (S1), U37.13 (B5)
R6: U34.4 (S1), U37.12 (B6)
R7: U35.4 (S1), U37.11 (B7)
R8: U35.1 (S2), U36.18 (B0)
R9: U35.13 (S3), U36.17 (B1)
R10: U35.10 (S4), U36.16 (B2)
R11: U27.4 (S1), U36.15 (B3)
R12: U27.1 (S2), U36.14 (B4)
R13: U27.13 (S3), U36.13 (B5)
R14: U27.10 (S4), U36.12 (B6)
R15: U27.9 (C4), U36.11 (B7)
~RI: CN1.32 (~RI), U19.2 (I1)
~RO: CN1.31 (~RO), U19.3 (I2)
~RST: CN1.5 (~RESET), U19.4 (I3/PD)

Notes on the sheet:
A5*B6
A6*B7
A5*B1
A2*B4
A1*B3
A1*B5
A2*B5
A1*B2
A3*B2
A2*B1
A2*B0
A2*B6
A4*B1
A4*B0
A0*B3
A6*B3
A4*B3
A7*B6
A0*B0
A2*B7
A5*B5
A7*B4
A7*B0
A4*B6
A6*B4
A3*B6
A3*B5
A7*B3
A2*B2
A4*B2
A1*B4
A3*B0
A5*B0
A5*B7
A1*B6
A0*B7
A4*B7
Mapped Addresses $FEx0 - Load A value with ~{RI} $FEx1 - Load B value with ~{RI} $FEx2 - Read result Low Byte with ~{RO} $FEx3 - Read result High Byte with ~{RO} 'x' is set with JP1-JP4, which defaults to x=$D
A0*B2
A6*B2

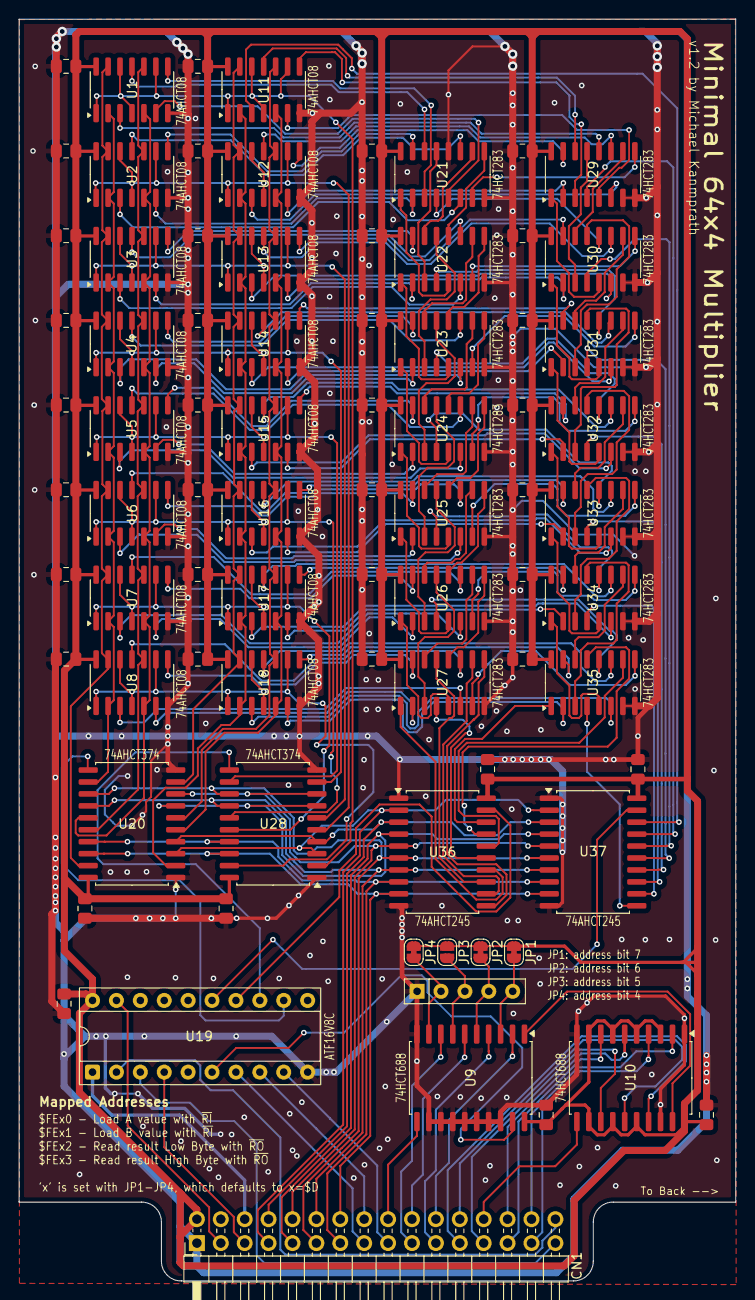
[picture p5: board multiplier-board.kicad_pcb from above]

Board: 2 copper layers, 76.2 x 134.1 mm, 80 parts (0 on the bottom side), 191 nets.

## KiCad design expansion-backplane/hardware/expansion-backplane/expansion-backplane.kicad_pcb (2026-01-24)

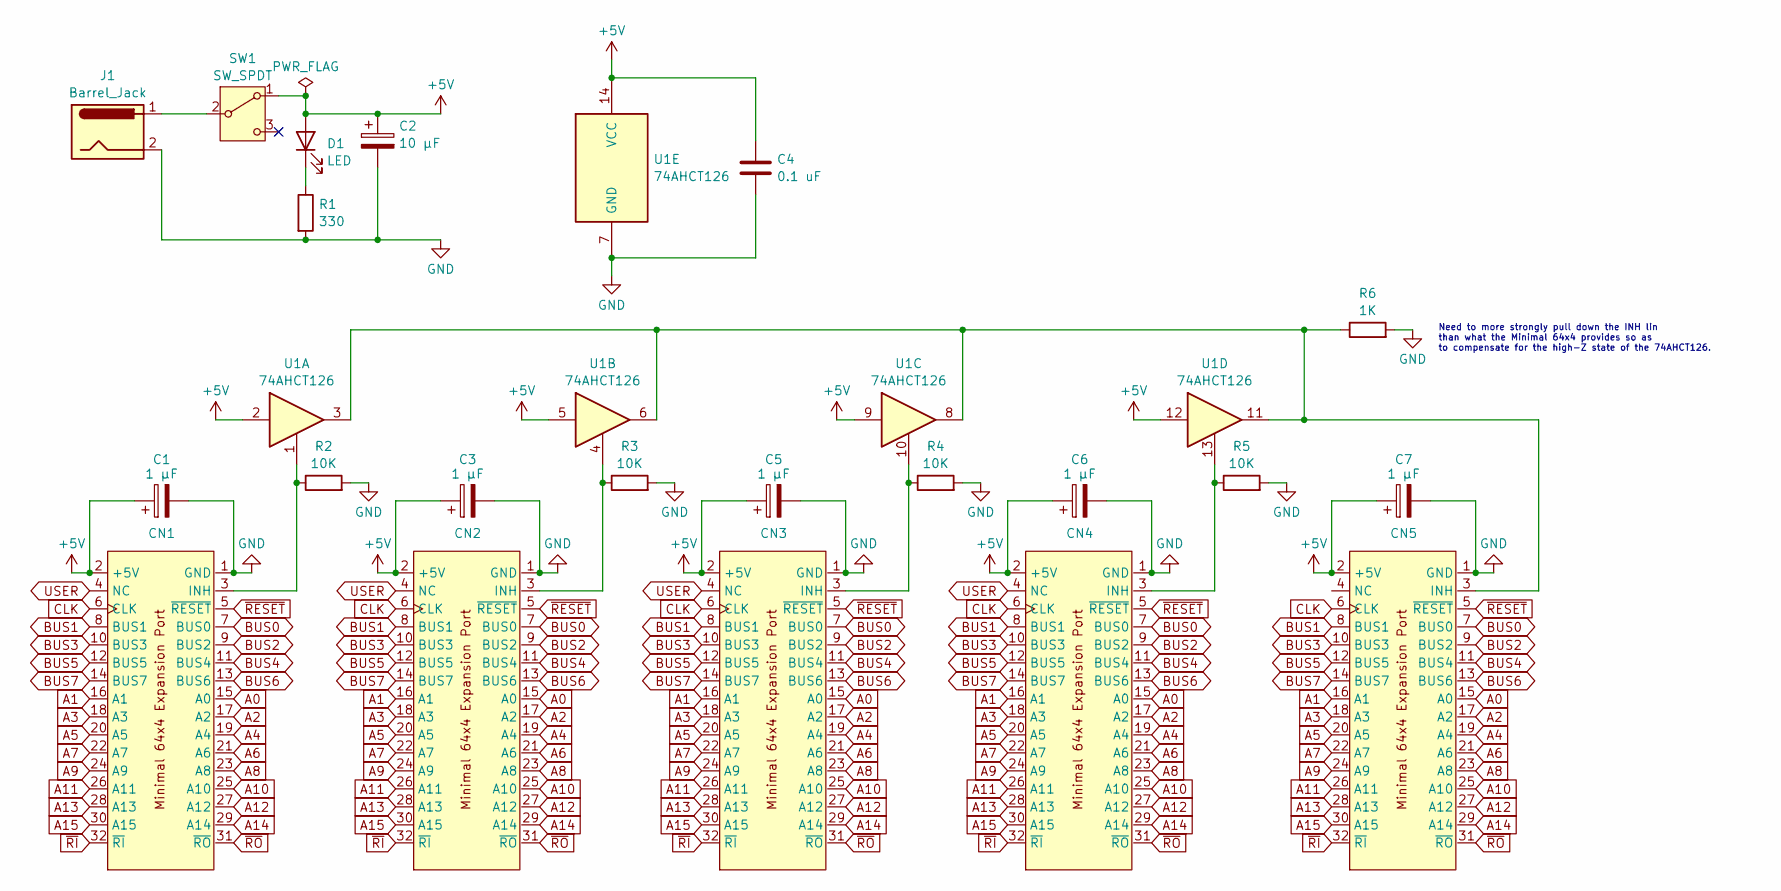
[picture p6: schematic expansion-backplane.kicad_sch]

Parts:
C1, C3, C5, C6, C7: 1 µF; CP_Radial_D4.0mm_P2.00mm
C2: 10 µF; CP_Radial_D5.0mm_P2.00mm
C4: 0.1 uF; C_Disc_D3.8mm_W2.6mm_P2.50mm
CN1, CN2, CN3, CN4, CN5: PinSocket_2x16_P2.54mm_Vertical
D1: LED; LED_D3.0mm
J1: Barrel_Jack; BarrelJack_Horizontal
R1: 330; R_Axial_DIN0207_L6.3mm_D2.5mm_P7.62mm_Horizontal
R2, R3, R4, R5: 10K; R_Axial_DIN0207_L6.3mm_D2.5mm_P7.62mm_Horizontal
R6: 1K; R_Axial_DIN0207_L6.3mm_D2.5mm_P7.62mm_Horizontal
SW1: SW_SPDT; E-Switch_200MSP1T2B2M6RE
U1: 74AHCT126; DIP-14_W7.62mm

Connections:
+5V: C1.1, C2.1, C3.1, C4.1, C5.1, C6.1, C7.1, CN1.2 (+5V), CN2.2 (+5V), CN3.2 (+5V), CN4.2 (+5V), CN5.2 (+5V), D1.2 (A), SW1.1 (A), U1.2, U1.5, U1.9, U1.12, U1.14 (VCC)
A0: CN1.15 (A0), CN2.15 (A0), CN3.15 (A0), CN4.15 (A0), CN5.15 (A0)
A1: CN1.16 (A1), CN2.16 (A1), CN3.16 (A1), CN4.16 (A1), CN5.16 (A1)
A2: CN1.17 (A2), CN2.17 (A2), CN3.17 (A2), CN4.17 (A2), CN5.17 (A2)
A3: CN1.18 (A3), CN2.18 (A3), CN3.18 (A3), CN4.18 (A3), CN5.18 (A3)
A4: CN1.19 (A4), CN2.19 (A4), CN3.19 (A4), CN4.19 (A4), CN5.19 (A4)
A5: CN1.20 (A5), CN2.20 (A5), CN3.20 (A5), CN4.20 (A5), CN5.20 (A5)
A6: CN1.21 (A6), CN2.21 (A6), CN3.21 (A6), CN4.21 (A6), CN5.21 (A6)
A7: CN1.22 (A7), CN2.22 (A7), CN3.22 (A7), CN4.22 (A7), CN5.22 (A7)
A8: CN1.23 (A8), CN2.23 (A8), CN3.23 (A8), CN4.23 (A8), CN5.23 (A8)
A9: CN1.24 (A9), CN2.24 (A9), CN3.24 (A9), CN4.24 (A9), CN5.24 (A9)
A10: CN1.25 (A10), CN2.25 (A10), CN3.25 (A10), CN4.25 (A10), CN5.25 (A10)
A11: CN1.26 (A11), CN2.26 (A11), CN3.26 (A11), CN4.26 (A11), CN5.26 (A11)
A12: CN1.27 (A12), CN2.27 (A12), CN3.27 (A12), CN4.27 (A12), CN5.27 (A12)
A13: CN1.28 (A13), CN2.28 (A13), CN3.28 (A13), CN4.28 (A13), CN5.28 (A13)
A14: CN1.29 (A14), CN2.29 (A14), CN3.29 (A14), CN4.29 (A14), CN5.29 (A14)
A15: CN1.30 (A15), CN2.30 (A15), CN3.30 (A15), CN4.30 (A15), CN5.30 (A15)
BUS0: CN1.7 (BUS0), CN2.7 (BUS0), CN3.7 (BUS0), CN4.7 (BUS0), CN5.7 (BUS0)
BUS1: CN1.8 (BUS1), CN2.8 (BUS1), CN3.8 (BUS1), CN4.8 (BUS1), CN5.8 (BUS1)
BUS2: CN1.9 (BUS2), CN2.9 (BUS2), CN3.9 (BUS2), CN4.9 (BUS2), CN5.9 (BUS2)
BUS3: CN1.10 (BUS3), CN2.10 (BUS3), CN3.10 (BUS3), CN4.10 (BUS3), CN5.10 (BUS3)
BUS4: CN1.11 (BUS4), CN2.11 (BUS4), CN3.11 (BUS4), CN4.11 (BUS4), CN5.11 (BUS4)
BUS5: CN1.12 (BUS5), CN2.12 (BUS5), CN3.12 (BUS5), CN4.12 (BUS5), CN5.12 (BUS5)
BUS6: CN1.13 (BUS6), CN2.13 (BUS6), CN3.13 (BUS6), CN4.13 (BUS6), CN5.13 (BUS6)
BUS7: CN1.14 (BUS7), CN2.14 (BUS7), CN3.14 (BUS7), CN4.14 (BUS7), CN5.14 (BUS7)
CLK: CN1.6 (CLK), CN2.6 (CLK), CN3.6 (CLK), CN4.6 (CLK), CN5.6 (CLK)
GND: C1.2, C2.2, C3.2, C4.2, C5.2, C6.2, C7.2, CN1.1 (GND), CN2.1 (GND), CN3.1 (GND), CN4.1 (GND), CN5.1 (GND), J1.2, R1.2, R2.2, R3.2, R4.2, R5.2, R6.2, U1.7 (GND)
unnamed: CN1.3 (INH), R2.1, U1.1
unnamed: CN2.3 (INH), R3.1, U1.4
unnamed: CN3.3 (INH), R4.1, U1.10
unnamed: CN4.3 (INH), R5.1, U1.13
unnamed: CN5.3 (INH), R6.1, U1.3, U1.6, U1.8, U1.11
unnamed: D1.1 (K), R1.1
unnamed: J1.1, SW1.2 (B)
USER: CN1.4 (NC), CN2.4 (NC), CN3.4 (NC), CN4.4 (NC)
~RESET: CN1.5 (~RESET), CN2.5 (~RESET), CN3.5 (~RESET), CN4.5 (~RESET), CN5.5 (~RESET)
~RI: CN1.32 (~RI), CN2.32 (~RI), CN3.32 (~RI), CN4.32 (~RI), CN5.32 (~RI)
~RO: CN1.31 (~RO), CN2.31 (~RO), CN3.31 (~RO), CN4.31 (~RO), CN5.31 (~RO)

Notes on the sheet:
Need to more strongly pull down the INH lin than what the Minimal 64x4 provides so as to compensate for the high-Z state of the 74AHCT126.

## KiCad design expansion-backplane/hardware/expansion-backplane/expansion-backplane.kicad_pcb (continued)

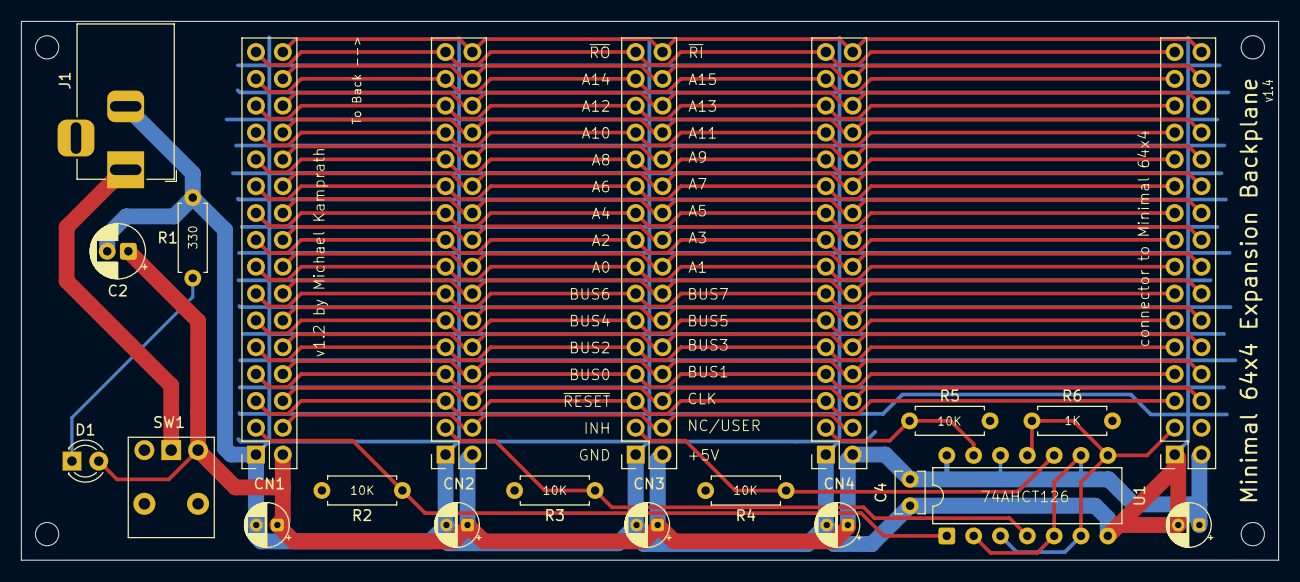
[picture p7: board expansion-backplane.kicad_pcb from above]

Board: 2 copper layers, 119.0 x 51.0 mm, 22 parts (0 on the bottom side), 38 nets.

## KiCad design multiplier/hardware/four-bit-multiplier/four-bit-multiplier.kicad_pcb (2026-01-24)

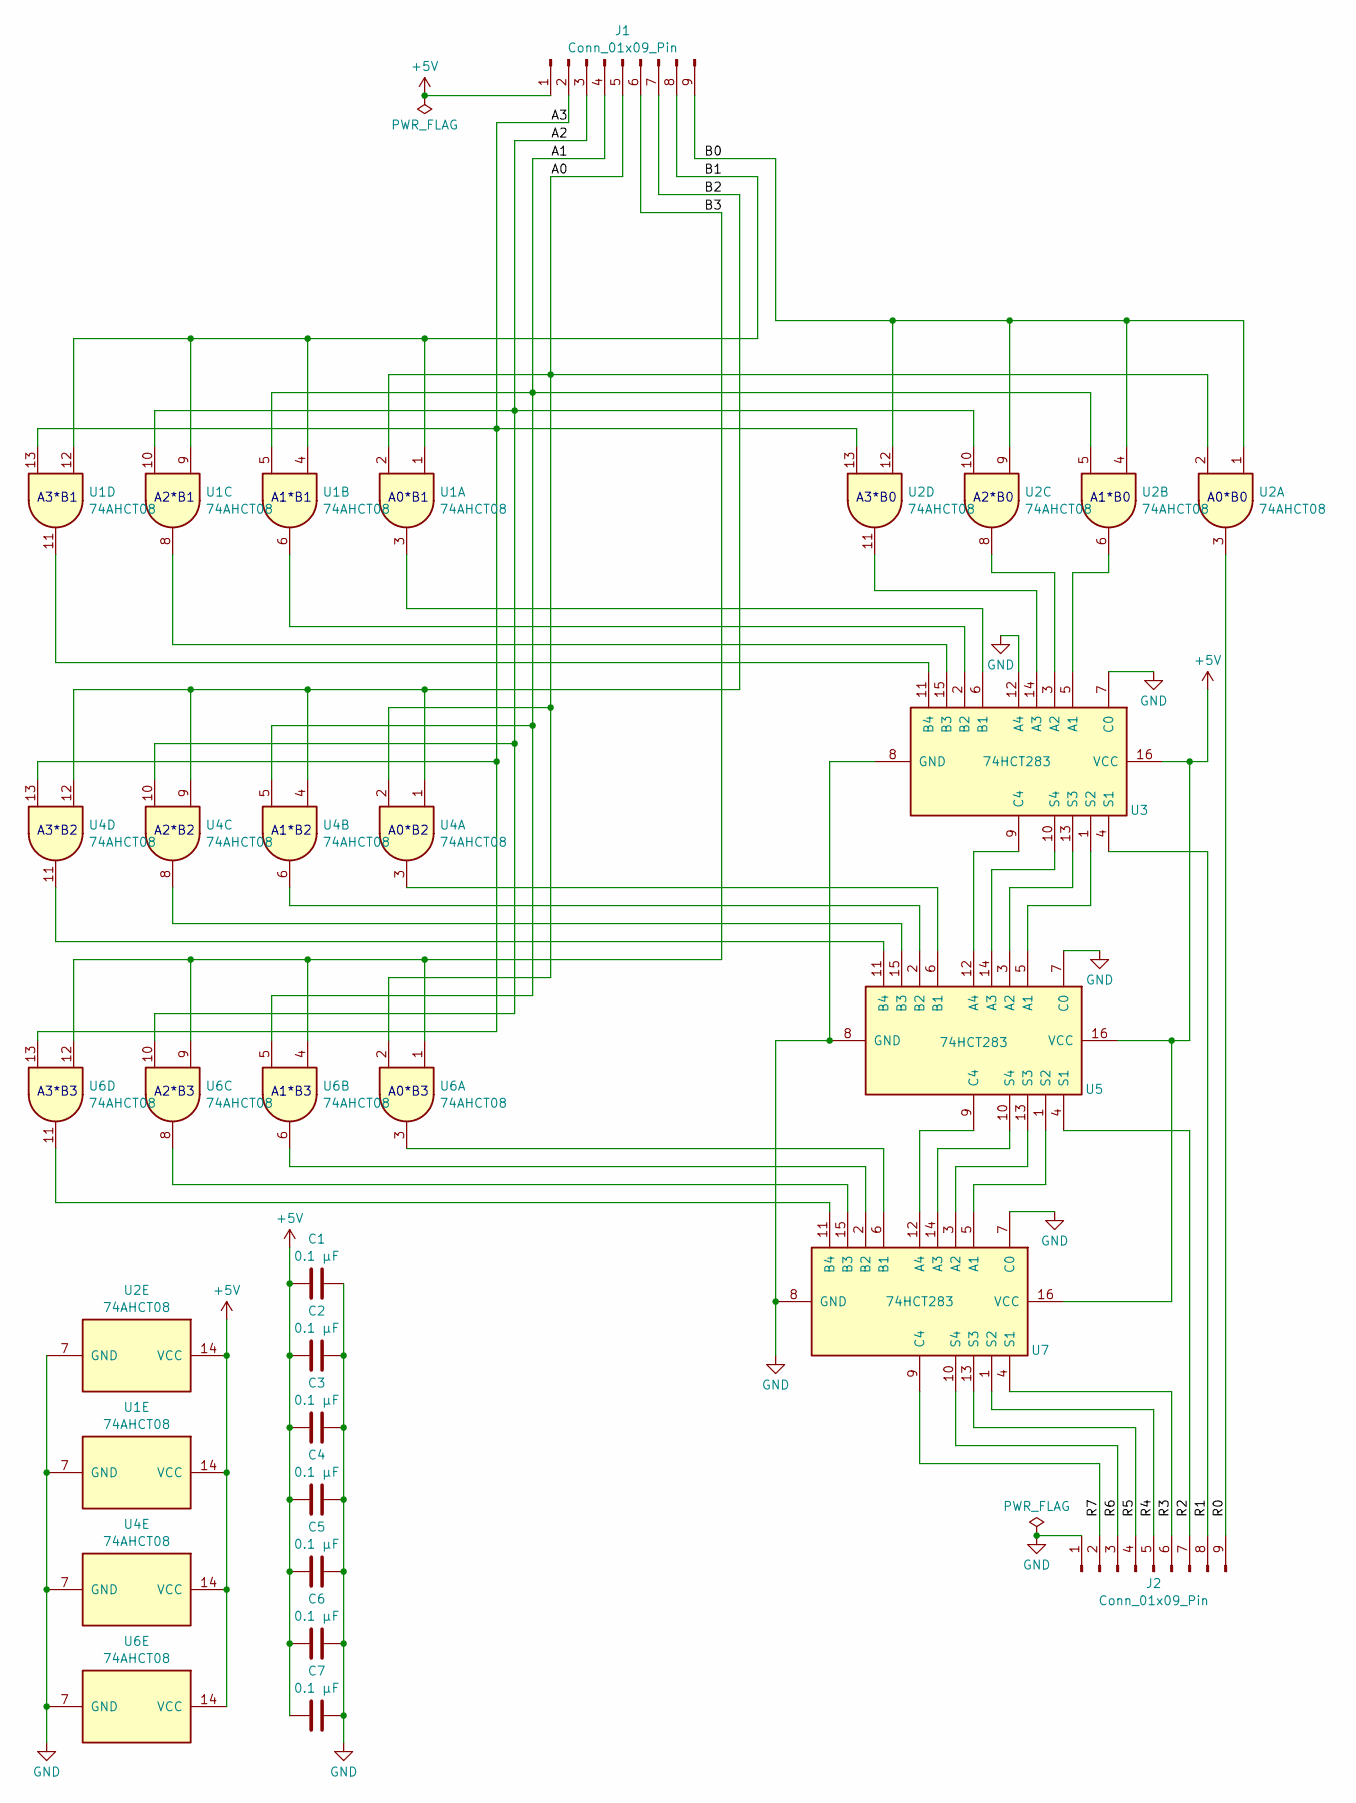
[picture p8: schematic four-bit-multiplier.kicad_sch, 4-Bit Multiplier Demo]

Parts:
C1, C2, C3, C4, C5, C6, C7: 0.1 µF; C_0805_2012Metric_Pad1.18x1.45mm_HandSolder
J1, J2: Conn_01x09_Pin; PinHeader_1x09_P2.54mm_Vertical
U1, U2, U4, U6: 74AHCT08; SOIC-14_3.9x8.7mm_P1.27mm
U3, U5, U7: 74HCT283; SOIC-16_3.9x9.9mm_P1.27mm

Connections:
+5V: C1.1, C2.1, C3.1, C4.1, C5.1, C6.1, C7.1, J1.1, U1.14 (VCC), U2.14 (VCC), U3.16 (VCC), U4.14 (VCC), U5.16 (VCC), U6.14 (VCC), U7.16 (VCC)
/A0: J1.5, U1.2, U2.2, U4.2, U6.2
/A1: J1.4, U1.5, U2.5, U4.5, U6.5
/A2: J1.3, U1.10, U2.10, U4.10, U6.10
/A3: J1.2, U1.13, U2.13, U4.13, U6.13
/B0: J1.9, U2.1, U2.4, U2.9, U2.12
/B1: J1.8, U1.1, U1.4, U1.9, U1.12
/B2: J1.7, U4.1, U4.4, U4.9, U4.12
/B3: J1.6, U6.1, U6.4, U6.9, U6.12
/R0: J2.9, U2.3
/R1: J2.8, U3.4 (S1)
/R2: J2.7, U5.4 (S1)
/R3: J2.6, U7.4 (S1)
/R4: J2.5, U7.1 (S2)
/R5: J2.4, U7.13 (S3)
/R6: J2.3, U7.10 (S4)
/R7: J2.2, U7.9 (C4)
GND: C1.2, C2.2, C3.2, C4.2, C5.2, C6.2, C7.2, J2.1, U1.7 (GND), U2.7 (GND), U3.7 (C0), U3.8 (GND), U3.12 (A4), U4.7 (GND), U5.7 (C0), U5.8 (GND), U6.7 (GND), U7.7 (C0), U7.8 (GND)
unnamed: U2.6, U3.5 (A1)
unnamed: U2.8, U3.3 (A2)
unnamed: U2.11, U3.14 (A3)
unnamed: U1.3, U3.6 (B1)
unnamed: U1.6, U3.2 (B2)
unnamed: U1.8, U3.15 (B3)
unnamed: U1.11, U3.11 (B4)
unnamed: U3.9 (C4), U5.12 (A4)
unnamed: U3.1 (S2), U5.5 (A1)
unnamed: U3.13 (S3), U5.3 (A2)
unnamed: U3.10 (S4), U5.14 (A3)
unnamed: U4.3, U5.6 (B1)
unnamed: U4.6, U5.2 (B2)
unnamed: U4.8, U5.15 (B3)
unnamed: U4.11, U5.11 (B4)
unnamed: U5.9 (C4), U7.12 (A4)
unnamed: U5.1 (S2), U7.5 (A1)
unnamed: U5.13 (S3), U7.3 (A2)
unnamed: U5.10 (S4), U7.14 (A3)
unnamed: U6.3, U7.6 (B1)
unnamed: U6.6, U7.2 (B2)
unnamed: U6.8, U7.15 (B3)
unnamed: U6.11, U7.11 (B4)

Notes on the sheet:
A3*B3
A1*B2
A1*B0
A0*B0
A2*B2
A2*B1
A1*B1
A1*B3
A2*B0
A3*B2
A2*B3
A0*B3
A3*B1
A3*B0
A0*B2
A0*B1

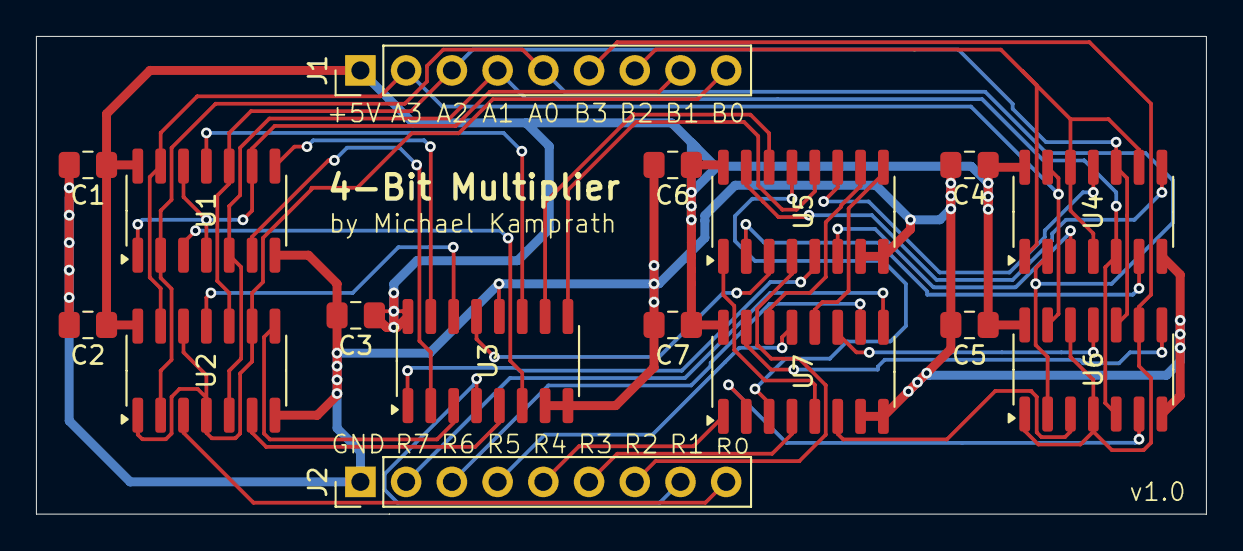
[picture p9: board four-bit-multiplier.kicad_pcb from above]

Board: 2 copper layers, 65.0 x 26.5 mm, 16 parts (0 on the bottom side), 41 nets.

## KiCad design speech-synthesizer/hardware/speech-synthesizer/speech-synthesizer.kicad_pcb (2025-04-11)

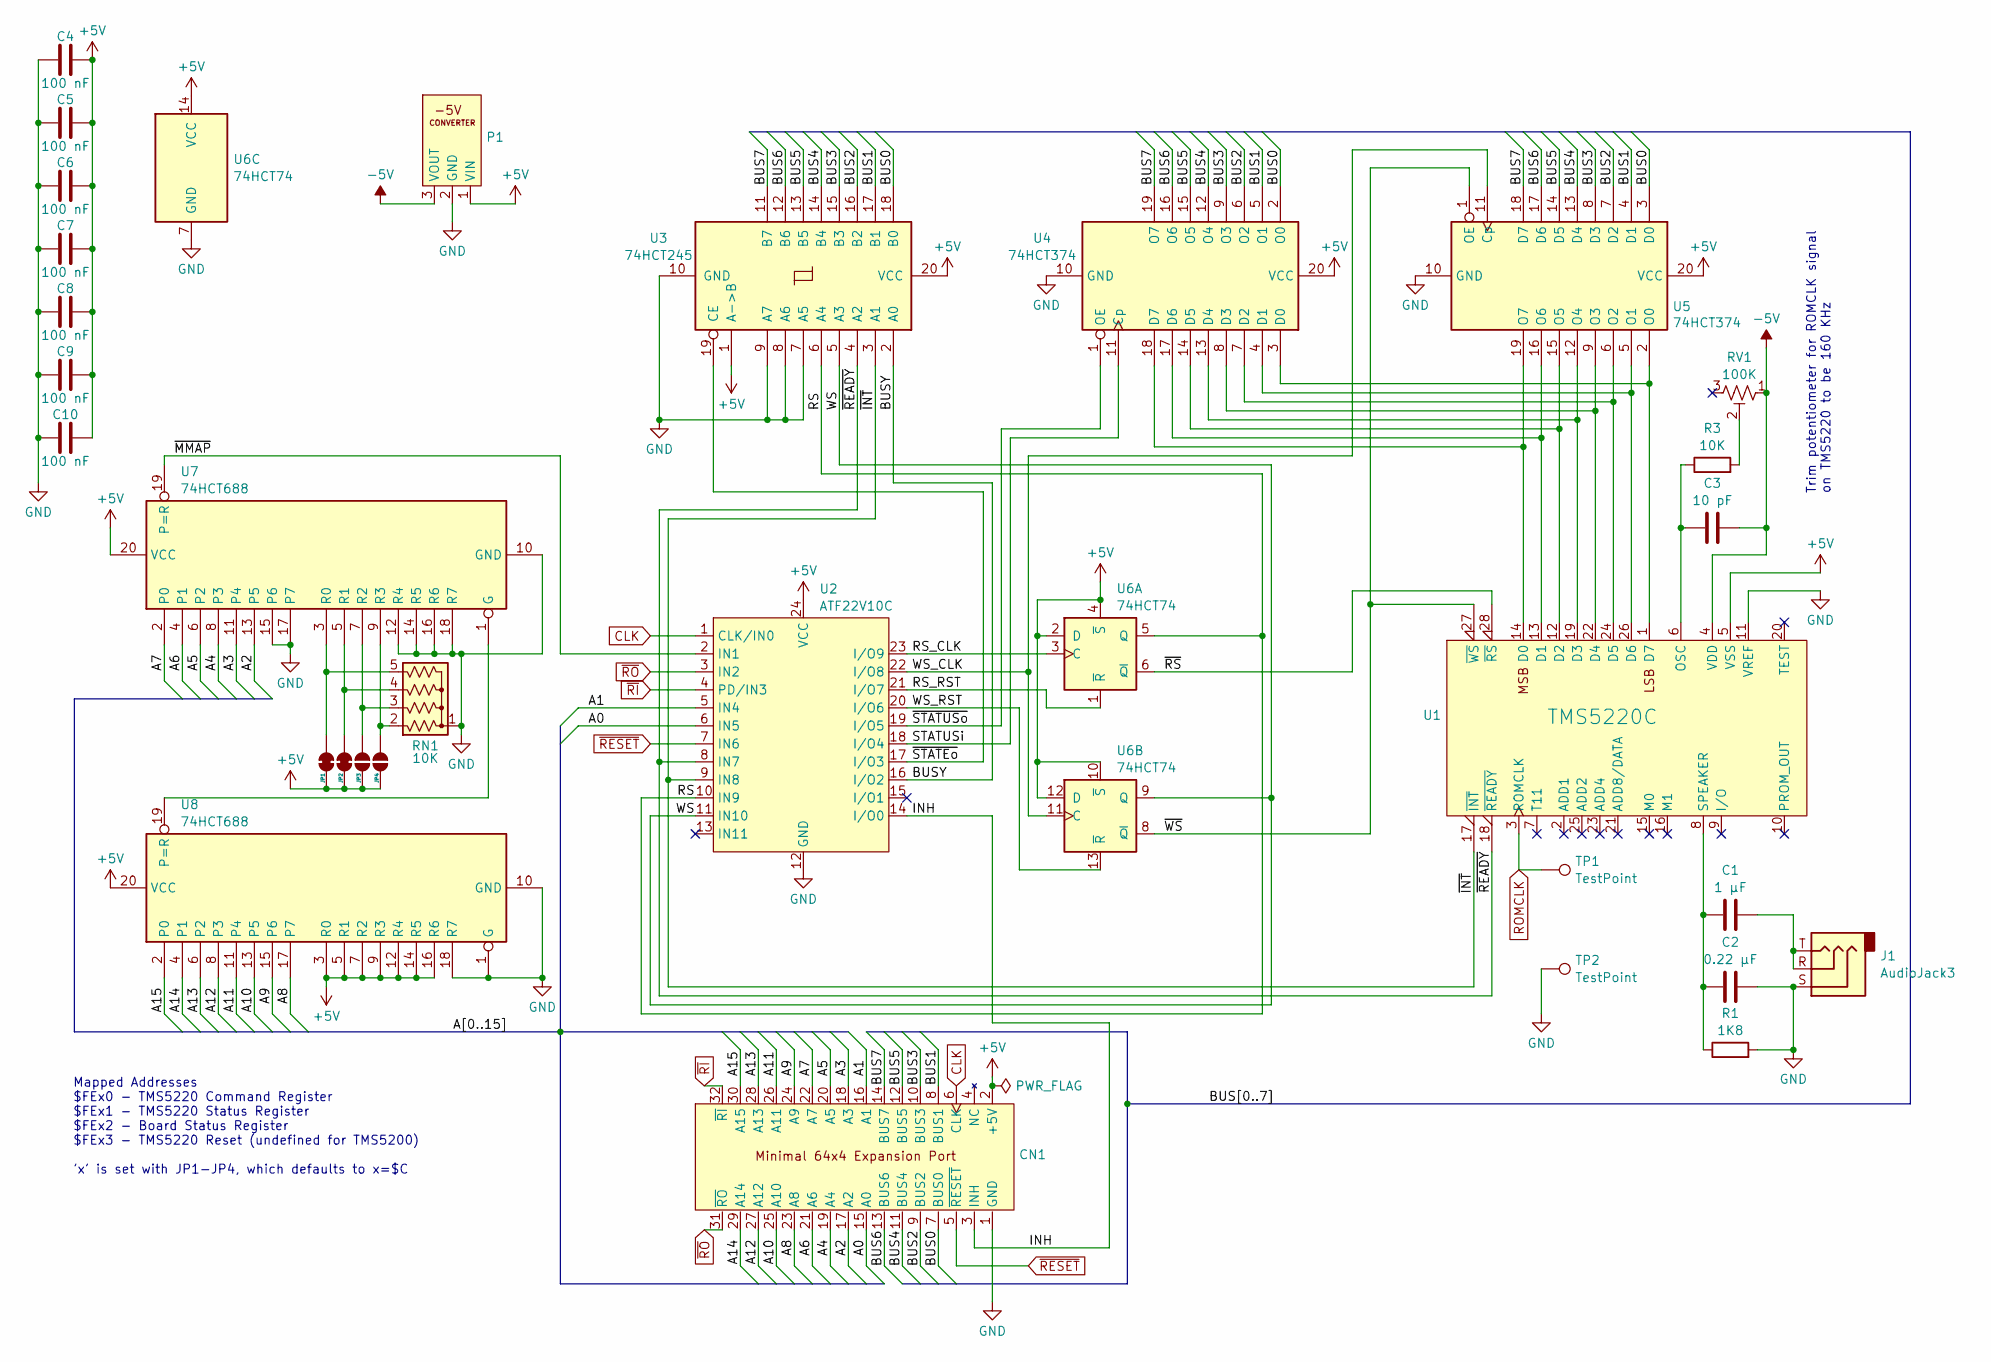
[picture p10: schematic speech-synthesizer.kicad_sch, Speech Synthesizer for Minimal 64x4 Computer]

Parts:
C1: 1 µF; C_Disc_D4.7mm_W2.5mm_P5.00mm
C2: 0.22 µF; C_Disc_D4.7mm_W2.5mm_P5.00mm
C3: 10 pF; C_Disc_D5.0mm_W2.5mm_P2.50mm
C4, C5, C6, C7, C8, C9, C10: 100 nF; C_Disc_D3.4mm_W2.1mm_P2.50mm
CN1: PinHeader_2x16_P2.54mm_Horizontal
J1: AudioJack3; Jack_3.5mm_CUI_SJ1-3523N_Horizontal
JP1, JP2: SolderJumper_2_Bridged; SolderJumper-2_P1.3mm_Bridged_RoundedPad1.0x1.5mm
JP3, JP4: SolderJumper_2_Open; SolderJumper-2_P1.3mm_Open_RoundedPad1.0x1.5mm
P1: -5V_Converter
R1: 1K8; R_Axial_DIN0207_L6.3mm_D2.5mm_P10.16mm_Horizontal
R3: 10K; R_Axial_DIN0207_L6.3mm_D2.5mm_P10.16mm_Horizontal
RN1: 10K; R_Array_SIP5
RV1: 100K; Potentiometer_Vishay_T73YP_Vertical
TP1, TP2: TestPoint; TestPoint_Pad_D2.0mm
U1: TMS5220C; DIP-28_W15.24mm_Socket
U2: ATF22V10C; DIP-24_W7.62mm_Socket
U3: 74HCT245; DIP-20_W7.62mm_Socket
U4, U5: 74HCT374; DIP-20_W7.62mm_Socket
U6: 74HCT74; DIP-14_W7.62mm_Socket
U7, U8: 74HCT688; DIP-20_W7.62mm_Socket

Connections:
+5V: C4.2, C5.2, C6.2, C7.2, C8.2, C9.2, C10.2, CN1.2 (+5V), JP1.1 (A), JP2.1 (A), JP3.1 (A), JP4.1 (A), P1.1 (VIN), U1.5 (VSS), U2.24 (VCC), U3.1 (A->B), U3.20 (VCC), U4.20 (VCC), U5.20 (VCC), U6.2 (D), U6.4 (~S), U6.10 (~S), U6.12 (D), U6.14 (VCC), U7.20 (VCC), U8.3 (R0), U8.5 (R1), U8.7 (R2), U8.9 (R3), U8.12 (R4), U8.14 (R5), U8.16 (R6), U8.20 (VCC)
-5V: C3.1, P1.3 (VOUT), RV1.1, U1.4 (VDD)
/A0: CN1.15 (A0), U2.6 (IN5)
/A1: CN1.16 (A1), U2.5 (IN4)
/A2: CN1.17 (A2), U7.13 (P5)
/A3: CN1.18 (A3), U7.11 (P4)
/A4: CN1.19 (A4), U7.8 (P3)
/A5: CN1.20 (A5), U7.6 (P2)
/A6: CN1.21 (A6), U7.4 (P1)
/A7: CN1.22 (A7), U7.2 (P0)
/A8: CN1.23 (A8), U8.17 (P7)
/A9: CN1.24 (A9), U8.15 (P6)
/A10: CN1.25 (A10), U8.13 (P5)
/A11: CN1.26 (A11), U8.11 (P4)
/A12: CN1.27 (A12), U8.8 (P3)
/A13: CN1.28 (A13), U8.6 (P2)
/A14: CN1.29 (A14), U8.4 (P1)
/A15: CN1.30 (A15), U8.2 (P0)
/BUS0: CN1.7 (BUS0), U3.18 (B0), U4.2 (O0), U5.3 (D0)
/BUS1: CN1.8 (BUS1), U3.17 (B1), U4.5 (O1), U5.4 (D1)
/BUS2: CN1.9 (BUS2), U3.16 (B2), U4.6 (O2), U5.7 (D2)
/BUS3: CN1.10 (BUS3), U3.15 (B3), U4.9 (O3), U5.8 (D3)
/BUS4: CN1.11 (BUS4), U3.14 (B4), U4.12 (O4), U5.13 (D4)
/BUS5: CN1.12 (BUS5), U3.13 (B5), U4.15 (O5), U5.14 (D5)
/BUS6: CN1.13 (BUS6), U3.12 (B6), U4.16 (O6), U5.17 (D6)
/BUS7: CN1.14 (BUS7), U3.11 (B7), U4.19 (O7), U5.18 (D7)
/BUSY: U2.16 (I/O2), U3.2 (A0)
/INH: CN1.3 (INH), U2.14 (I/O0)
/RS: U2.10 (IN9), U3.6 (A4), U6.5 (Q)
/RS_CLK: U2.23 (I/O9), U6.3 (C)
/RS_RST: U2.21 (I/O7), U6.1 (~R)
/STATUSi: U2.18 (I/O4), U4.11 (Cp)
/WS: U2.11 (IN10), U3.5 (A3), U6.9 (Q)
/WS_CLK: U2.22 (I/O8), U5.11 (Cp), U6.11 (C)
/WS_RST: U2.20 (I/O6), U6.13 (~R)
/~INT: U1.17 (~INT), U2.9 (IN8), U3.3 (A1)
/~MMAP: U2.2 (IN1), U7.19 (P=R)
/~READY: U1.18 (~READY), U2.8 (IN7), U3.4 (A2)
/~RS: U1.28 (~RS), U6.6 (~Q)
/~STATEo: U2.17 (I/O3), U3.19 (CE)
/~STATUSo: U2.19 (I/O5), U4.1 (OE)
/~WS: U1.27 (~WS), U5.1 (OE), U6.8 (~Q)
CLK: CN1.6 (CLK), U2.1 (CLK/IN0)
GND: C2.2, C4.1, C5.1, C6.1, C7.1, C8.1, C9.1, C10.1, CN1.1 (GND), J1.S, P1.2 (GND), R1.2, RN1.1 (common), TP2.1, U1.11 (VREF), U2.12 (GND), U3.7 (A5), U3.8 (A6), U3.9 (A7), U3.10 (GND), U4.10 (GND), U5.10 (GND), U6.7 (GND), U7.10 (GND), U7.12 (R4), U7.14 (R5), U7.15 (P6), U7.16 (R6), U7.17 (P7), U7.18 (R7), U8.1 (G), U8.10 (GND), U8.18 (R7)
unnamed: C1.2, J1.R, J1.T
unnamed: JP1.2 (B), RN1.5 (R4), U7.3 (R0)
unnamed: JP2.2 (B), RN1.4 (R3), U7.5 (R1)
unnamed: JP3.2 (B), RN1.3 (R2), U7.7 (R2)
unnamed: JP4.2 (B), RN1.2 (R1), U7.9 (R3)
unnamed: R3.2, RV1.2
unnamed: U1.14 (D0), U4.18 (D7), U5.19 (O7)
unnamed: U1.13 (D1), U4.17 (D6), U5.16 (O6)
unnamed: U1.12 (D2), U4.14 (D5), U5.15 (O5)
unnamed: U1.19 (D3), U4.13 (D4), U5.12 (O4)
unnamed: U1.22 (D4), U4.8 (D3), U5.9 (O3)
unnamed: U1.24 (D5), U4.7 (D2), U5.6 (O2)
unnamed: U1.26 (D6), U4.4 (D1), U5.5 (O1)
unnamed: U1.1 (D7), U4.3 (D0), U5.2 (O0)
unnamed: C3.2, R3.1, U1.6 (OSC)
unnamed: C1.1, C2.1, R1.1, U1.8 (SPEAKER)
unnamed: U7.1 (G), U8.19 (P=R)
ROMCLK: TP1.1, U1.3 (ROMCLK)
~RESET: CN1.5 (~RESET), U2.7 (IN6)
~RI: CN1.32 (~RI), U2.4 (PD/IN3)
~RO: CN1.31 (~RO), U2.3 (IN2)

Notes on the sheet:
Trim potentiometer for ROMCLK signal on TMS5220 to be 160 KHz
Mapped Addresses $FEx0 - TMS5220 Command Register $FEx1 - TMS5220 Status Register $FEx2 - Board Status Register $FEx3 - TMS5220 Reset (undefined for TMS5200) 'x' is set with JP1-JP4, which defaults to x=$C

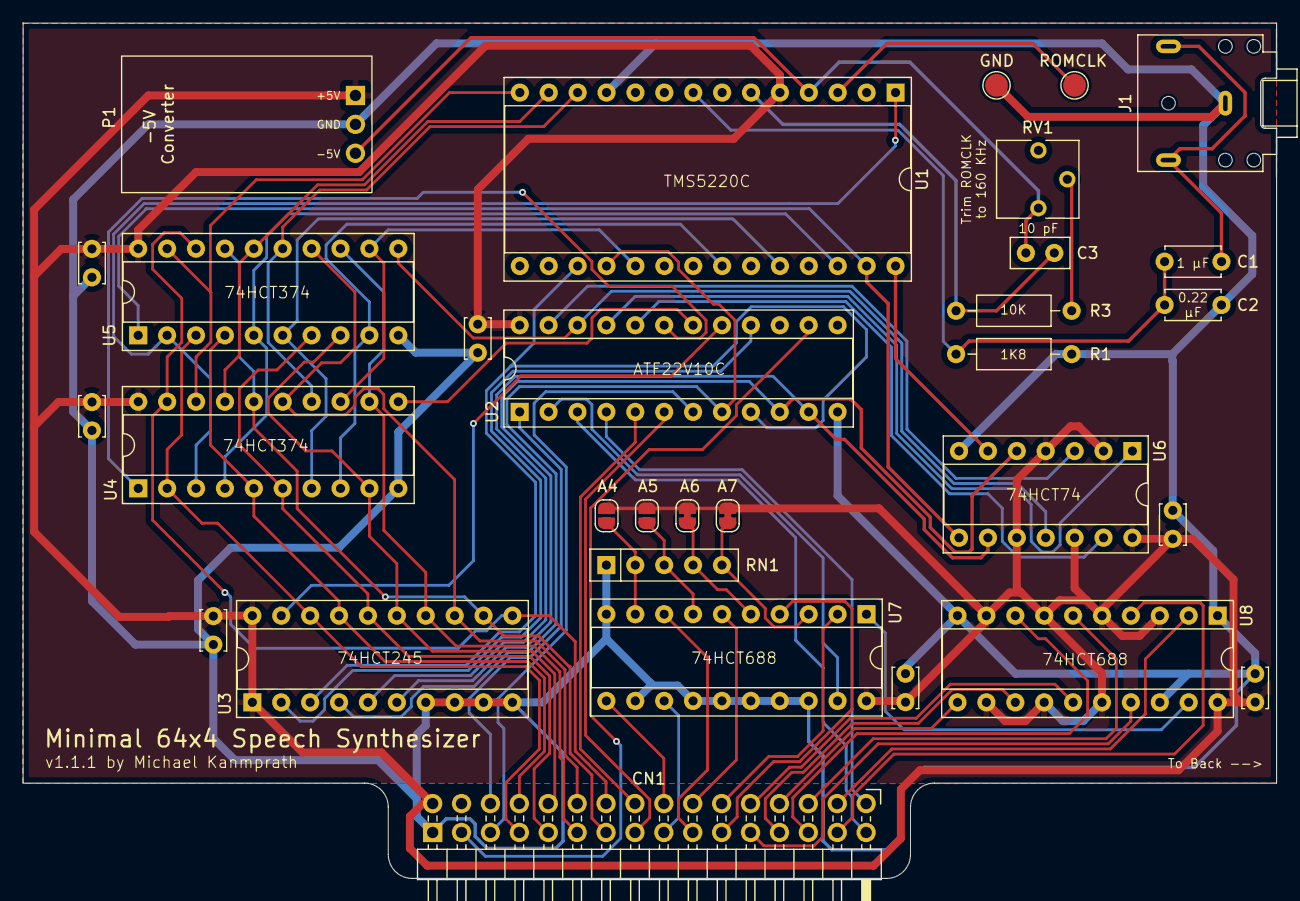
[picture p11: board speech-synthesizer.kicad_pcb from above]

Board: 2 copper layers, 110.2 x 75.2 mm, 31 parts (0 on the bottom side), 65 nets.

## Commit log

2024-12-25 speech synthizer setup
    [speech-synthesizer.kicad_pcb, speech-synthesizer.kicad_sch]
2024-12-25 added backplane
    [expansion-backplane.kicad_pcb, expansion-backplane.kicad_sch, speech-synthesizer.kicad_sch]
2024-12-25 added expansion connector
    [expansion-backplane.kicad_sch, expansion-connector.kicad_pcb, expansion-connector.kicad_sch]
2024-12-25 updatedd PCB layouts
    [expansion-backplane.kicad_pcb, expansion-connector.kicad_pcb, expansion-connector.kicad_sch]
2024-12-25 created speech pcb
    [speech-synthesizer.kicad_pcb]
2024-12-25 updated documentation
    [speech-synthesizer.kicad_pcb]
2024-12-25 update speech pld file and more
    [expansion-backplane.kicad_pcb, expansion-connector.kicad_pcb, speech-synthesizer.kicad_pcb]
2024-12-25 added sample code for speech
2024-12-25 improved backplane
    [expansion-backplane.kicad_pcb, expansion-backplane.kicad_sch, speech-synthesizer.kicad_pcb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]
2024-12-25 added speech samples
2024-12-25 added pull down resistors
    [expansion-backplane.kicad_pcb, expansion-backplane.kicad_sch]
2024-12-25 removed barier mosfet
    [speech-synthesizer.kicad_sch]
2024-12-29 improved silkscreen
    [speech-synthesizer.kicad_pcb]
2024-12-29 added pull down resistor
    [expansion-backplane.kicad_pcb, expansion-backplane.kicad_sch]
2025-01-01 added BOM
    [bom-speech-synthesizer.csv]
2025-04-11 update kicad version
    [bom-speech-synthesizer.csv, expansion-backplane.kicad_pcb, expansion-backplane.kicad_sch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]
2025-07-04 first schematice of 4-bit multiplier
    [four-bit-multiplier.kicad_pcb, four-bit-multiplier.kicad_sch]
2025-07-04 fixed carry
    [four-bit-multiplier.kicad_sch]
2025-08-18 first version of multiplier board
    [expansion-backplane.kicad_pcb, four-bit-multiplier.kicad_pcb, four-bit-multiplier.kicad_sch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]
2025-08-18 corrected part designator
    [multiplier-board.kicad_pcb, multiplier-board.kicad_sch]
2025-08-25 start of software for multiplier board
2025-08-28 added controller PLD
    [multiplier-board.kicad_sch]
2025-08-31 corrected issues
    [multiplier-board.kicad_pcb]
2025-09-01 added better ground plane
    [expansion-backplane.kicad_pcb, expansion-connector.kicad_pcb]
2025-09-02 updated version
    [expansion-backplane.kicad_pcb, expansion-connector.kicad_pcb]
2025-09-07 changed pcb to 4-layer with internal ground planes
    [multiplier-board.kicad_pcb]
2026-01-17 improved signal line isolation
    [multiplier-board.kicad_pcb]
2026-01-18 improved signal integrity
    [multiplier-board.kicad_pcb]
2026-01-24 Hardware Multiplier (#1)
    Created a hardware multiplier for the Minimal 64x4
    [expansion-backplane.kicad_pcb, expansion-connector.kicad_pcb, four-bit-multiplier.kicad_pcb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]
2026-03-07 Timer Card (#4)
    Adds a clock counting Timer Card.
    [timer.kicad_pcb, timer.kicad_sch]
2026-04-05 improved timer card design
    [timer.kicad_pcb, timer.kicad_sch]
2026-04-30 small tweaks
    [timer.kicad_pcb]
2026-05-02 improved timer pld
2026-08-03 move timer card to $FE28 to stop bus contention with multiplier
    At $FEF0 the timer differed from the multipliers $FED0 in a single
    decoded address bit (A5). A slow address line during a bus transition
    let the timer decode a multiplier access and drive the data bus against
    it, corrupting result reads intermittently in accelerator builds only.
    $FE28 differs in all five decoded bits (A7..A3).
    Add test_karatsuba_layers, test_multiplier_exhaustive and test_ram
    diagnostics. Drop mathlib64 (unused), test_multiplier (superseded) and
    rotating_wireframe (no longer builds).
